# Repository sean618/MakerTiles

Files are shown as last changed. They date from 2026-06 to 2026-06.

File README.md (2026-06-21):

# MakerTiles

MakerTiles is a system of modular, snap-together electronic tiles. Each tile is a
small STM32-based board with a single job — a strip of LEDs, a joystick, a motor,
a distance sensor, a screen, a speaker, and so on. Tiles connect on a shared bus,
a USB tile bridges the bus to a PC, and a Python daemon on the PC discovers every
connected tile and lets you read its inputs and drive its outputs.

This repository holds the whole stack: the **hardware** (KiCad board designs), the
**firmware** (STM32 board projects + shared driver libraries), the **protocols**
that move data over the bus, and the **daemon** that talks to it all from a PC.

```
    [ tile ]──[ tile ]──[ tile ]── … ──[ USB tile ]──USB──▶ [ PC / Python daemon ]
       └───────────────────────────────────┘
          shared SPI bus  (MicroBus + Field Protocol)
```

## How it fits together

Two protocols stacked on top of each other carry everything:

- **MicroBus** — the transport. A master/multi-node protocol over a shared
  SPI-style link between microcontrollers, built for speed and very low RAM:
  fixed-size packets, a time-slotted schedule the master broadcasts in every
  packet, and a small per-node sliding window that gives reliable, in-order
  delivery with no dynamic allocation.
- **Field Protocol** — the application layer. Rides inside a MicroBus packet and
  describes each tile as a set of named, typed **fields** (e.g. a LED strip's
  colour, a dial's position). The daemon enumerates tiles, reads their field
  tables, and gets/sets field values without knowing the tile type in advance.

One tile acts as the **master** (the USB tile, which also bridges the bus to a
host PC). Every other tile is a **node**. On the PC, the daemon opens the USB
serial port, discovers the attached tiles, and exposes each one as an object you
can interact with.

## Repository layout

```
hardware/        KiCad designs for every tile (Boards/) + shared symbol/footprint
                 libraries, 3D models and BOMs (Libraries/). Old/ holds retired
                 prototype boards.

firmware/        STM32 firmware.
  Boards/          One STM32CubeIDE project per tile (Button, LedStrip, Motor,
                   Joystick, Screen, USB, …). Mostly STM32G030 nodes; the USB
                   master is an STM32F103.
  Libraries/       Shared C/C++ drivers used across boards (ledStrip, screen,
                   imu, speaker, servos, …) plus helpers (myAssert, fonts).
  Documents/       NewBoardSetup.txt — the checklist for bringing up a new tile
                   (CubeMX peripheral config + firmware wiring).

protocol/        The shared protocol code, host-buildable and testable.
  microbus/        MicroBus transport (C++). Leaf component.
  fieldprotocol/   Field Protocol (C++), depends on microbus. Also built as the
                   masterNodeSystem shared library the Python daemon loads.
  stm32/           STM32 glue binding the protocols to real SPI hardware
                   (stm32F1SpiMaster, stm32Node). Boards reach this via a
                   Core/stm32 symlink.

daemon/          Python daemon (the PC side). Opens the USB serial port, runs
                   board discovery, and drives tiles over the Field Protocol.
                   src/makertiles/ is the package; tests/ holds its test suites.

tests/system/    Full C stack (node + master) over the real MicroBus, in-process.

tools/           Helper scripts (e.g. logparser.py).
```

## The PC daemon

The daemon is a Python package (`makertiles`, src-layout under `daemon/`). At a
high level you point it at a serial port and it hands you back the discovered
tiles:

```python
import makertiles

tiles, manager = makertiles.start(port_name="/dev/ttyUSB0")

tiles.led_strip.colour = makertiles.red   # set an output field
position = tiles.dial.position             # read an input field
```

It can drive the C protocol two ways: over **serial** to real hardware in
production, or — in tests — by loading the `masterNodeSystem` shared library
directly via `ctypes`, so the real Python daemon exercises the real C protocol
without any hardware attached. That same library is what catches drift between
the C and Python sides of the wire contract.

Optional extras: `Pillow` (`images`) for the screen image-drawing helpers.

## Building and testing

The C components and the Python daemon build in one CMake tree, and every test
suite runs from a single command:

```bash
./build_and_test.sh
```

This configures, builds (MicroBus, the Field Protocol + its shared library, and
the system test), then runs `ctest`. Python test deps (`pytest`, `pyserial`) are
installed automatically if missing.

To re-run only the failures, verbosely:

```bash
ctest --test-dir build --rerun-failed --output-on-failure
```

### Test suites

| CTest name | What it covers |
|---|---|
| `microbus_unit` | MicroBus transport unit tests (host). |
| `fieldprotocol_unit` | Field Protocol unit tests against a mock MicroBus. |
| `system_integration` | Full C stack (node + master) over the real MicroBus. |
| `python_unit` | Python Field-Protocol encode/decode round trips. |
| `python_integration` | The real Python daemon driving the C protocol via the .so.  |

`python_integration` is the suite that exercises both languages together, so it
is the one that catches C↔Python wire-contract drift.

The firmware board projects under `firmware/Boards/` are separate
STM32CubeIDE/CMake projects and are **not** part of the host build above — they
are flashed to real tiles. See `firmware/Documents/NewBoardSetup.txt` for the
per-board hardware and firmware bring-up checklist.

## Building firmware for a tile

Each `firmware/Boards/<Tile>/` directory is its own STM32 project (`.ioc` for
CubeMX, a linker script for the target part, and CubeIDE debug launch configs).
Nodes are generally STM32G030; the USB master is an STM32F103. The protocol
sources are shared into each board via symlinks (`Core/stm32`,
`Core/Libraries`, etc.) rather than copied — see the setup checklist for the
exact links and the required SPI/timer/interrupt peripheral configuration.

## License

Released under the [MIT License](LICENSE).

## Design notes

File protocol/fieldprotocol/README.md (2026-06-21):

# Field Protocol (C++23)

An idiomatic C++23 port of the Field Protocol firmware/daemon library. The code
implements a small field-discovery and get/set protocol between a daemon, a bus
master, and many nodes, with a wire format that is preserved byte-for-byte from
the original.

## Building

The project builds under **both `g++` and `clang++`** as standards-conformant
C++23 (no compiler extensions).

### With CMake

```bash
./build.sh            # configures + builds into ./build
cd build && ctest     # runs the test executable
```

This produces two artifacts:

- `fieldprotocol_tests` — the test executable (built with `USE_FP_DAEMON` and
  `USE_MOCK_MICROBUS`). Running it prints `Passed` on success.
- `libmasterNodeSystem` — the shared library exposing the `extern "C"` entry
  points the Python daemon loads via `ctypes` (built with `USE_MOCK_MICROBUS`
  only; no C++ daemon).

### Without CMake

`build_and_test.sh` builds both targets directly with a compiler of your choice
and asserts the suite prints `Passed`:

```bash
./build_and_test.sh g++ clang++   # build + test under both
CXX=g++ ./build_and_test.sh       # or pick one via $CXX
```

## Layout

- `src/` — the protocol library, header-only: `fpCommon.hpp`, `fpNode.hpp`,
  `fpMaster.hpp`, `fpDaemon.hpp`. Each class is fully defined (declaration and
  implementation) in its header, so consumers just `#include` it.
- `test/` — test drivers, board fixtures, and the three interchangeable
  transports (direct-call, mock microbus, real microbus) plus the Python API
  shim (`pythonApi.cpp`).

## What changed from the C version

The original was C-style code compiled as C++. The port keeps the on-the-wire
behaviour identical while adopting modern C++ idioms:

- Everything lives in `namespace fp`. C headers (`stdint.h`, …) became their
  `<cstdint>` equivalents; `NULL` became `nullptr`; casts are now
  `static_cast`/`reinterpret_cast`. `fpCommon.hpp` pulls the fixed-width integer
  types into scope with `using` declarations, so the code writes `uint8_t`
  rather than `std::uint8_t`.
- Tag enums became scoped `enum class : uint8_t`. `FieldFlags` gained
  `operator|`/`&` and `isGettable`/`isSettable`/`isJoined` helpers. The X-macro
  command table became a `commandName()` function.
- The transport, previously a struct of four function pointers plus an opaque
  `void* state`, is now the abstract base class `FpInterface`; each transport
  (mock, direct-call, microbus) derives from it and owns its own state. The old
  `getNodeId` callback folded into a virtual method.
- `tFpNode`/`tFpMaster`/`tFpDaemon` became the classes `Node`/`Master`/`Daemon`
  with `init(...)` constructors-in-spirit and member functions in place of the
  free `fpXxx(&obj, …)` functions. The master's two callbacks became
  `std::function`s.
- Board and field strings became `std::string`, which removed the daemon's
  manual `malloc`/`free` bookkeeping. The daemon now owns discovered boards via
  `std::unique_ptr`.
- The packed wire structs keep `#pragma pack` and their exact field order, so
  `RawBusFieldPacket` (6-byte header + 186-byte payload) and
  `RawDaemonFieldPacket` are byte-identical to the original.

Two latent out-of-bounds reads in the original test fixtures (an 8-byte field
backed by a 1-byte variable, and a 2-byte-element stream backed by a 1-byte
array) were fixed by widening the backing storage to match the declared field
sizes; the wire bytes and field tables are otherwise unchanged.

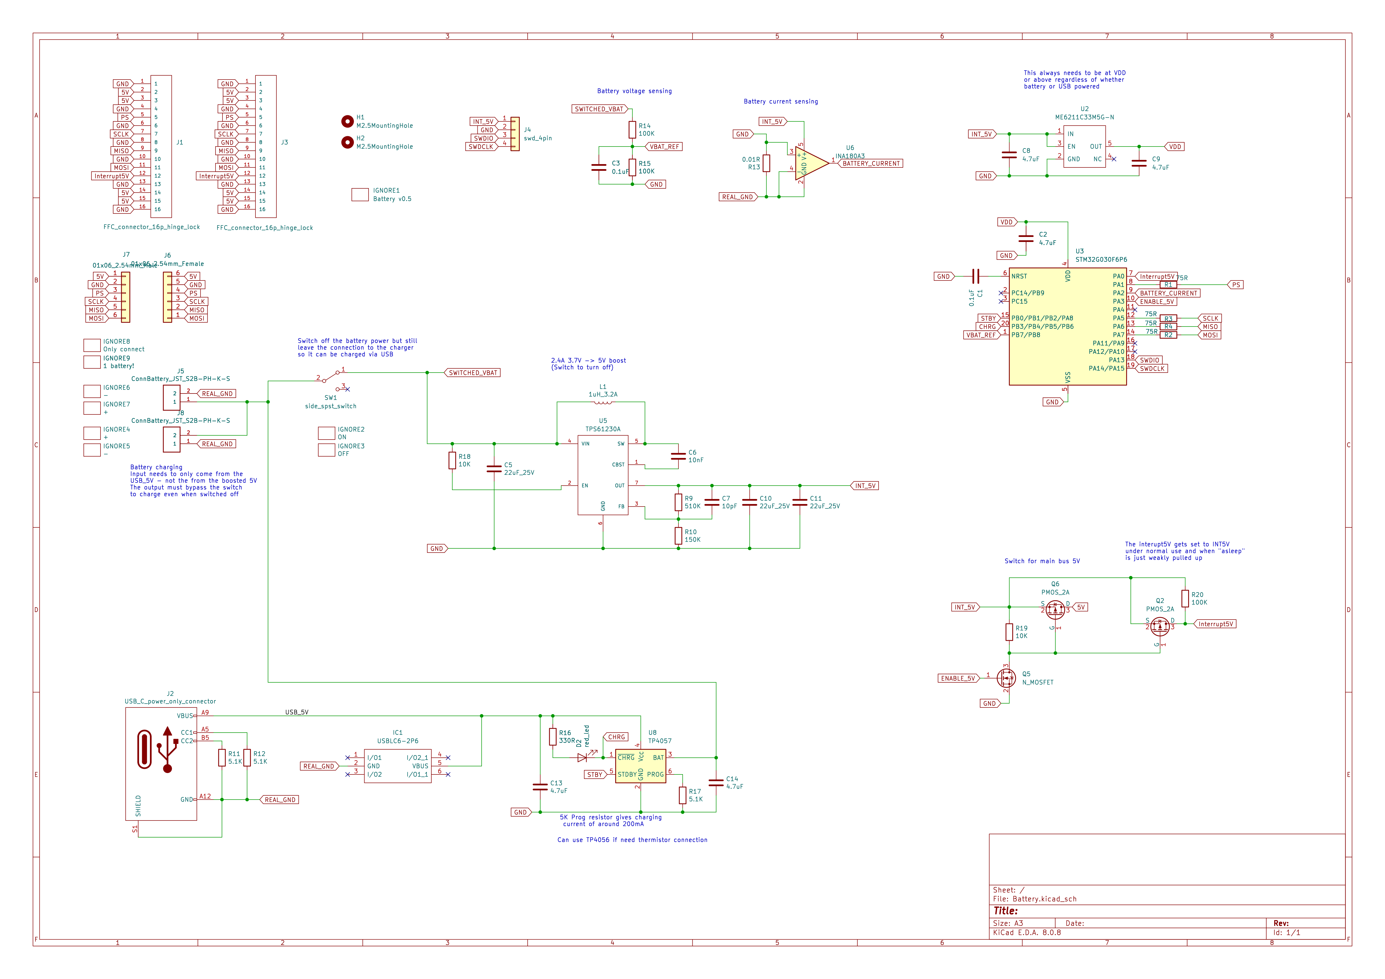
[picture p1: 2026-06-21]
hardware/Boards/Battery/v0.10/Battery.png

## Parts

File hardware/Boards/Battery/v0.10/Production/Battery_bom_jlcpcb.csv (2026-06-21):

Comment | Designator | Footprint | LCSC Part Number
4.7uF | C9,C4,C13,C14,C8,C2 | C_0402_1005Metric | C23733
FFC_connector_16p_hinge_lock | J1,J3 | FFC_connector_16p_hinge_lock | C262665
0.01R | R13 | R_0805_2012Metric | C2912728
PMOS_2A | Q6,Q2 | SOT-23 | C306862
22uF_25V | C10,C5,C11 | C_0805_2012Metric | C602037
red_led | D2 | LED_SML-D12D1WT86 | C2286
side_spst_switch | SW1 | side_spst_switch | C431548
10pF | C7 | C_0402_1005Metric | C32949
ConnBattery_JST_S2B-PH-K-S | J5,J8 | JST_PH_S2B-PH-K_1x02_P2.00mm_Horizontal | C173752
USB_C_power_only_connector | J2 | USB_C_Receptacle_power_only_6P | C283540
INA180A3 | U6 | SOT-23-5 | C122882
USBLC6-2P6 | IC1 | USBLC6-2P6 | C2827693
TP4057 | U8 | SOT-23-6 | C5380673
10K | R5,R6,R18,R19 | R_0402_1005Metric | C25744
TPS61230A | U5 | TPS61230A | C376005
ME6211C33M5G-N | U2 | SOT-23-5 | C81233
0.1uF | C1,C3,C12 | C_0402_1005Metric | C1525
150K | R10 | R_0402_1005Metric | C25755
510K | R9 | R_0402_1005Metric | C11616
330R | R16 | R_0402_1005Metric | C25104
75R | R2,R3,R4,R1 | R_0402_1005Metric | C25133
XB7608AJ | U4 | XB7608AJ | C2681921
STM32G030F6P6 | U3 | TSSOP-20_4.4x6.5mm_P0.65mm | C529330
5.1K | R12,R17,R11 | R_0402_1005Metric | C25905
100K | R15,R14,R20 | R_0402_1005Metric | C25741
1uH_3.2A | L1 | L_1008_2520Metric | C315711
1K | R7 | R_0402_1005Metric | C11702
N_MOSFET | Q5 | SOT-23 | C8545
TPS2116DRL | U1 | SOT-583-8 | C3235557
10nF | C6 | C_0402_1005Metric | C15195
01x06_2.54mm_Female | J6 | 01x06_2.54mm_Female | C5142239
01x06_2.54mm_Male | J7 | 01x06_2.54mm_Male | C5242199

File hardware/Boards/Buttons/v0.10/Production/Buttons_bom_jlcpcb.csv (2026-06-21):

Comment | Designator | Footprint | LCSC Part Number
4.7uF | C9,C8,C2 | C_0402_1005Metric | C23733
FFC_connector_16p_hinge_lock | J5,J3 | FFC_connector_16p_hinge_lock | C262665
button_6x6x7 | SW1,SW2,SW4,SW3,SW6 | SW_SPST_PTS645 | C381064
10K | R9,R6,R8,R5,R7 | R_0402_1005Metric | C25744
ME6211C33M5G-N | U2 | SOT-23-5 | C81233
75R | R2,R3,R4,R1 | R_0402_1005Metric | C25133
STM32G030F6P6 | U3 | TSSOP-20_4.4x6.5mm_P0.65mm | C529330
0.1uF | C1 | C_0402_1005Metric | C1525
1N4148W | D2 | D_SOD-123 | C81598
01x06_2.54mm_Male | J1 | 01x06_2.54mm_Male | C5242199
01x06_2.54mm_Female | J2 | 01x06_2.54mm_Female | C5142239

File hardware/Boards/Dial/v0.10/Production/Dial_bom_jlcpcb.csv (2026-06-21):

Comment | Designator | Footprint | LCSC Part Number
4.7uF | C9,C8,C2 | C_0402_1005Metric | C23733
FFC_connector_16p_hinge_lock | J1,J2 | FFC_connector_16p_hinge_lock | C262665
STM32C011F6Px | U3 | TSSOP-20_4.4x6.5mm_P0.65mm | C5456198
1N4148W | D2 | D_SOD-123 | C81598
ME6211C33M5G-N | U2 | SOT-23-5 | C81233
75R | R2,R4,R1,R3 | R_0402_1005Metric | C25133
RotaryEncoder_Switch | SW7 | RotaryEncoderEC12D | C112349
10K | R5 | R_0402_1005Metric | C25744
0.1uF | C1 | C_0402_1005Metric | C1525
01x06_2.54mm_Female | J5 | 01x06_2.54mm_Female | C5142239
01x06_2.54mm_Male | J3 | 01x06_2.54mm_Male | C5242199

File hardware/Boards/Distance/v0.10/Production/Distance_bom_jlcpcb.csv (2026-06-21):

Comment | Designator | Footprint | LCSC Part Number
4.7uF | C9,C8,C5,C3,C4 | C_0402_1005Metric | C23733
12pF | C6,C7 | C_0402_1005Metric | C1547
FFC_connector_16p_hinge_lock | J3,J5 | FFC_connector_16p_hinge_lock | C262665
75R | R8,R10,R9,R7 | R_0402_1005Metric | C25133
0.1uF | C11 | C_0402_1005Metric | C1525
10K | R5,R6 | R_0402_1005Metric | C25744
STM32F103C8T6 | U3 | LQFP-48_7x7mm_P0.5mm | C8734
ME6211C33M5G-N | U2 | SOT-23-5 | C81233
VL53L3CXV0DH | U1 | VL53L3CXV0DH | C1864163
Crystal_16M_small | Y1 | Crystal_SMD_2016-4Pin_2.0x1.6mm | C252270
01x06_2.54mm_Male | J1 | 01x06_2.54mm_Male | C5242199
01x06_2.54mm_Female | J2 | 01x06_2.54mm_Female | C5142239

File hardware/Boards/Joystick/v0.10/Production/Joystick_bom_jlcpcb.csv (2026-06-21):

Comment | Designator | Footprint | LCSC Part Number
4.7uF | C9,C8,C2 | C_0402_1005Metric | C23733
Joystick | U1 | Joystick | C146170
FFC_connector_16p_hinge_lock | J5,J2 | FFC_connector_16p_hinge_lock | C262665
ME6211C33M5G-N | U2 | SOT-23-5 | C81233
75R | R2,R4,R1,R3 | R_0402_1005Metric | C25133
STM32G030F6P6 | U3 | TSSOP-20_4.4x6.5mm_P0.65mm | C529330
10K | R6 | R_0402_1005Metric | C25744
0.1uF | C1 | C_0402_1005Metric | C1525
01x06_2.54mm_Male | J1 | 01x06_2.54mm_Male | C5242199
01x06_2.54mm_Female | J3 | 01x06_2.54mm_Female | C5142239

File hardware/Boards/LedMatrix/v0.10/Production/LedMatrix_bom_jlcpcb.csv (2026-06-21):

Comment | Designator | Footprint | LCSC Part Number
WS2812B | D34,D48,D12,D2,D37,D47,D39,D42,D11,D3,D18,D16,D15,D29,D17,D38,D28,D4,D36,D43,D21,D14,D26,D24,D8,D22,D40,D32,D6,D10,D49,D44,D41,D35,D31,D33,D20,D30,D46,D9,D27,D13,D23,D1,D25,D19,D7,D5,D45 | LED_WS2812B_PLCC4_5.0x5.0mm_P3.2mm | C2843785
N_MOSFET | Q1 | SOT-23 | C8545
STM32G030F6P6 | U2 | TSSOP-20_4.4x6.5mm_P0.65mm | C529330
FFC_connector_16p_hinge_lock | J4,J5 | FFC_connector_16p_hinge_lock | C262665
22uF_10V | C8,C6,C11,C15,C16,C7,C13,C12 | C_0603_1608Metric | C86295
4.7uF | C3,C2,C1 | C_0402_1005Metric | C23733
75R | R1,R3,R5,R6 | R_0402_1005Metric | C25133
1K | R4,R2 | R_0402_1005Metric | C11702
01x06_2.54mm_Male | J1 | 01x06_2.54mm_Male | C5242199
0.1uF | C4 | C_0402_1005Metric | C1525
ME6211C33M5G-N | U1 | SOT-23-5 | C81233
01x06_2.54mm_Female | J2 | 01x06_2.54mm_Female | C5142239

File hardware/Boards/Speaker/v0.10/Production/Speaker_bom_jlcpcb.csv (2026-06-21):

Comment | Designator | Footprint | LCSC Part Number
SpeakerSmt | LS2 | Speaker1.8x1.8 | C48542868
FFC_connector_16p_hinge_lock | J12,J13 | FFC_connector_16p_hinge_lock | C262665
2p_picoblade | J2 | Molex_PicoBlade_53261-0271_1x02-1MP_P1.25mm_Horizontal | C2905009
4.7uF | C9,C11,C8,C12 | C_0402_1005Metric | C23733
220pF | C10,C4 | C_0402_1005Metric | C1530
75R | R7,R4,R9,R6 | R_0402_1005Metric | C25133
01x06_2.54mm_Male | J1 | 01x06_2.54mm_Male | C5242199
01x06_2.54mm_Female | J3 | 01x06_2.54mm_Female | C5142239
ME6211C33M5G-N | U2 | SOT-23-5 | C81233
750K | R2 | R_0402_1005Metric | C43291
0.1uF | C15 | C_0402_1005Metric | C1525
STM32G030F6P6 | U3 | TSSOP-20_4.4x6.5mm_P0.65mm | C529330
MAX98357AEWL+T | U1 | WLP-9_1.448x1.468mm_Layout3x3_P0.4mm_Ball0.27mm_Pad0.25mm | C2682619

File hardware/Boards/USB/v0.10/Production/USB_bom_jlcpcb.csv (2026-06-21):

Comment | Designator | Footprint | LCSC Part Number
4.7uF | C9,C2,C8,C5,C1 | C_0402_1005Metric | C23733
1.5K | R12 | R_0402_1005Metric | C25867
12pF | C6,C7 | C_0402_1005Metric | C1547
FFC_connector_16p_hinge_lock | J5,J6 | FFC_connector_16p_hinge_lock | C262665
STM32F103C8T6 | U1 | LQFP-48_7x7mm_P0.5mm | C8734
75R | R7,R4,R5,R6 | R_0402_1005Metric | C25133
ME6211C33M5G-N | U2 | SOT-23-5 | C81233
5.1K | R2,R1 | R_0402_1005Metric | C25905
USBLC6-4SC6 | IC1 | SOT-23-6 | C558419
Crystal_16M_small | Y2 | Crystal_SMD_2016-4Pin_2.0x1.6mm | C252270
0.1uF | C4 | C_0402_1005Metric | C1525
USB_C_connector_16P | J2 | USB_C_Receptacle_16P | C319148
01x06_2.54mm_Male | J1 | 01x06_2.54mm_Male | C5242199
01x06_2.54mm_Female | J3 | 01x06_2.54mm_Female | C5142239

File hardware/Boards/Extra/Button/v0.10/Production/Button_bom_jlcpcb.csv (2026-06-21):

Comment | Designator | Footprint | LCSC Part Number
4.7uF | C9,C8,C2 | C_0402_1005Metric | C23733
FFC_connector_16p_hinge_lock | J1,J3 | FFC_connector_16p_hinge_lock | C262665
10K | R5 | R_0402_1005Metric | C25744
button_6x6x7 | SW2 | SW_SPST_PTS645 | C381064
1K | R6 | R_0402_1005Metric | C11702
ME6211C33M5G-N | U2 | SOT-23-5 | C81233
1N4148W | D3 | D_SOD-123 | C81598
75R | R2,R3,R4,R1 | R_0402_1005Metric | C25133
STM32G030F6P6 | U3 | TSSOP-20_4.4x6.5mm_P0.65mm | C529330
ws2812b_1615 | D2 | WS2812B_1615 | C5349954
N_MOSFET | Q1 | SOT-23 | C8545
0.1uF | C1 | C_0402_1005Metric | C1525
01x06_2.54mm_Female | J5 | 01x06_2.54mm_Female | C5142239
01x06_2.54mm_Male | J2 | 01x06_2.54mm_Male | C5242199

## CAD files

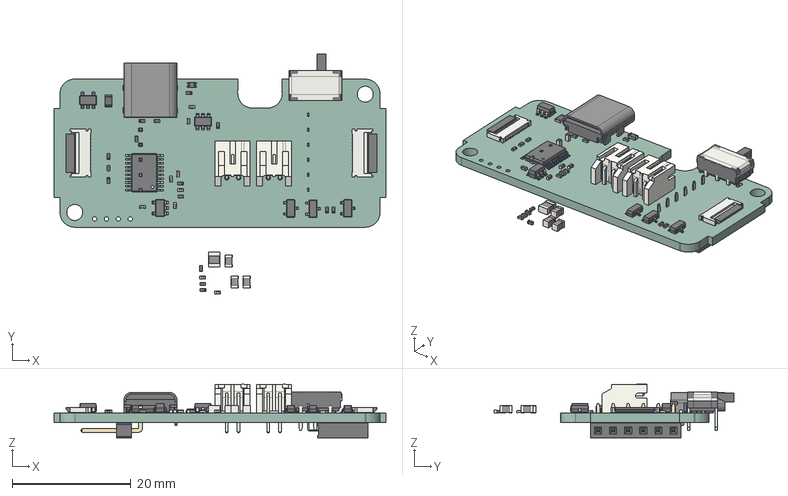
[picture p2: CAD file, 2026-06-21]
hardware/Boards/Battery/v0.10/Battery.step
56.0 x 40.5 x 9.09 mm
C_0402_1005Metric x 9
Molex_502250_2191 x 2
R_0805_2012Metric
SOT_23 x 3
C_0805_2012Metric x 3
D_0603
SW_CuK_JS202011AQN_DPDT_Angled
JST_S2B_PH_K x 2
USB_C_Receptacle_GCT_USB4085
SOT_23_5 x 2
SOT_23_6
R_0402_1005Metric x 15
TSSOP_20_44x65mm_P065mm
L_1008_2520Metric
PinSocket_1x06_P2.54mm_Horizontal
PinHeader_1x06_P254mm_Horizontal
Battery_PCB

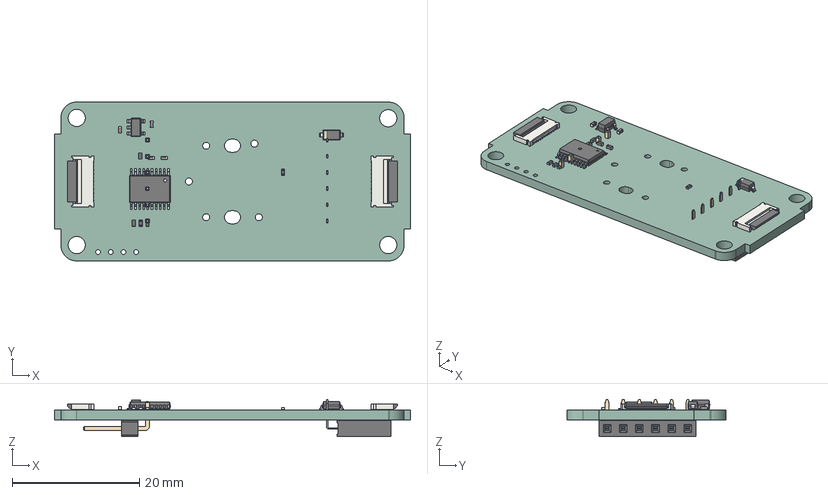
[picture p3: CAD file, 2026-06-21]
hardware/Boards/Dial/v0.10/Dial.step
56.0 x 25.0 x 5.84 mm
C_0402_1005Metric x 4
Molex_502250_2191 x 2
D_SOD_123
SOT_23_5
R_0402_1005Metric x 5
TSSOP_20_44x65mm_P065mm
PinSocket_1x06_P2.54mm_Horizontal
PinHeader_1x06_P254mm_Horizontal
Dial_PCB

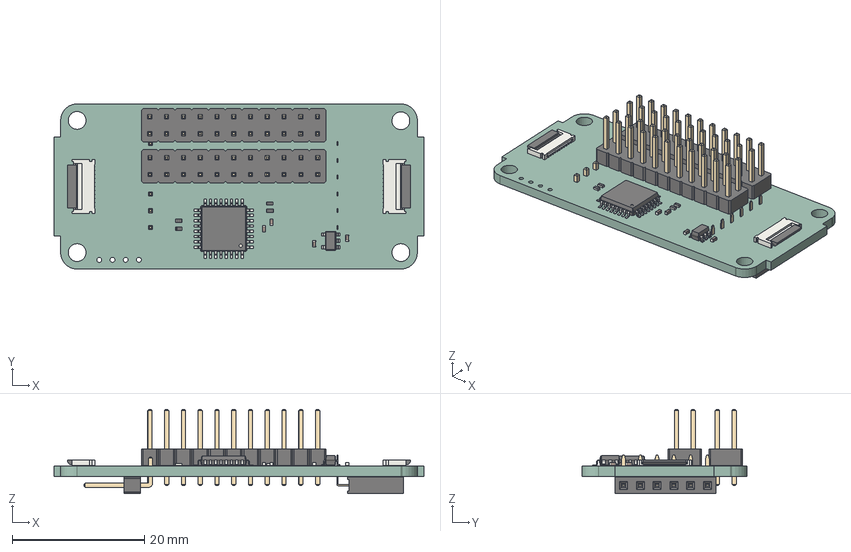
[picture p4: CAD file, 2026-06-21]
hardware/Boards/Extra/ButtonExpansion/v0.5/ButtonExpansion.step
56.0 x 25.0 x 12.8 mm
C_0402_1005Metric x 4
Molex_502250_2191 x 2
R_0402_1005Metric x 4
PinHeader_2x11_P254mm_Vertical x 2
SOT_23_5
LQFP_32_7x7mm_P08mm
PinHeader_1x06_P254mm_Horizontal
PinSocket_1x06_P2.54mm_Horizontal
ButtonExpansion_PCB

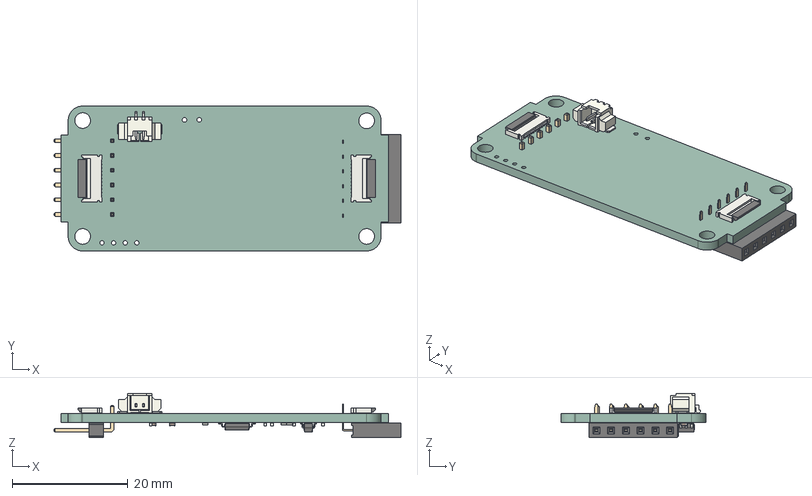
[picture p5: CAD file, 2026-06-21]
hardware/Boards/Speaker/v0.10/Speaker.step
59.9 x 25.0 x 7.64 mm
Molex_502250_2191 x 2
Molex_53261_0271
C_0402_1005Metric x 7
R_0402_1005Metric x 5
PinHeader_1x06_P254mm_Horizontal
PinSocket_1x06_P2.54mm_Horizontal
SOT_23_5
TSSOP_20_44x65mm_P065mm
Speaker_PCB

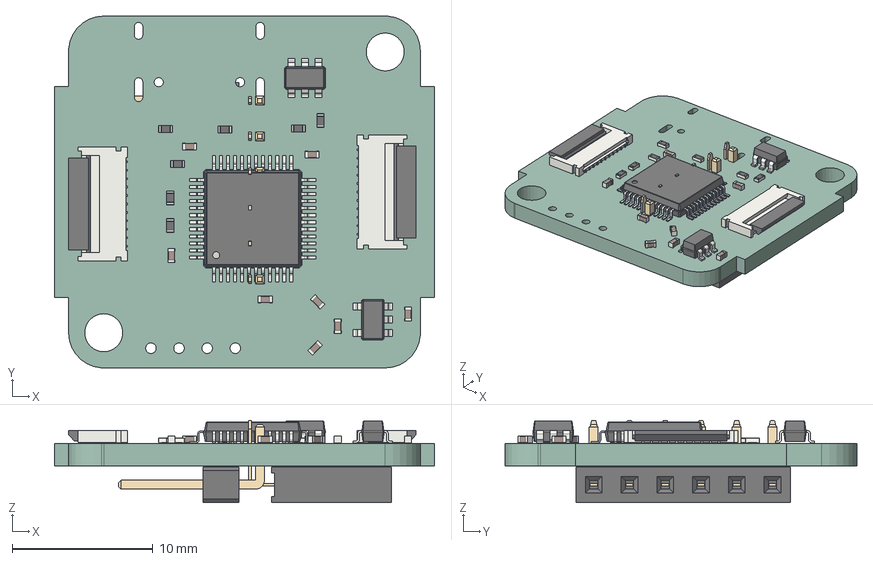
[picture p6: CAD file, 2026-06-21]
hardware/Boards/USB/v0.10/USB.step
27.0 x 25.0 x 5.84 mm
C_0402_1005Metric x 8
R_0402_1005Metric x 7
Molex_502250_2191 x 2
LQFP_48_7x7mm_P05mm
SOT_23_5
SOT_23_6
PinHeader_1x06_P254mm_Horizontal
PinSocket_1x06_P2.54mm_Horizontal
USB_PCB

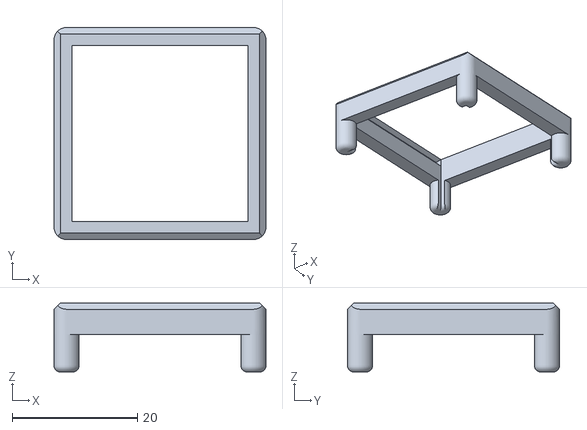
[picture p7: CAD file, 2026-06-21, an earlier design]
hardware/Boards/Battery/v0.5/Ring.stl
33.8 x 33.8 x 11.0

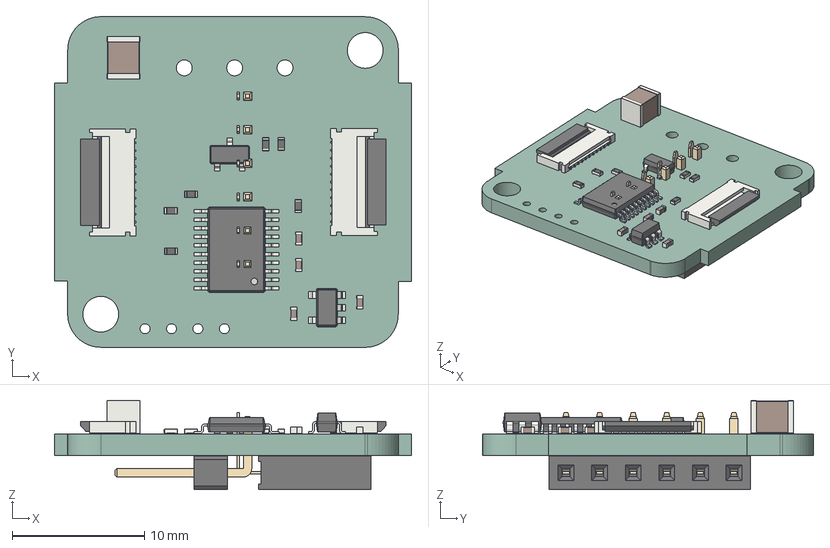
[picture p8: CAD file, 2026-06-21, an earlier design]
hardware/Boards/LED/v0.10/LED.step
27.0 x 25.0 x 6.74 mm
C_0402_1005Metric x 4
Molex_502250_2191 x 2
C_1210_3225Metric
R_0402_1005Metric x 6
SOT_23_5
SOT_23
TSSOP_20_44x65mm_P065mm
PinHeader_1x06_P254mm_Horizontal
PinSocket_1x06_P2.54mm_Horizontal
LED_PCB

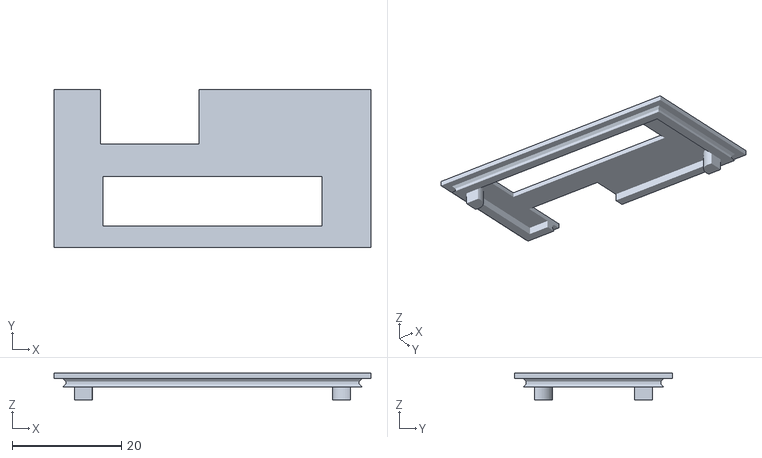
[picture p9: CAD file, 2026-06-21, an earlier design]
hardware/Boards/Motor/v0.7/MotorLid.stl
58.0 x 29.0 x 4.90

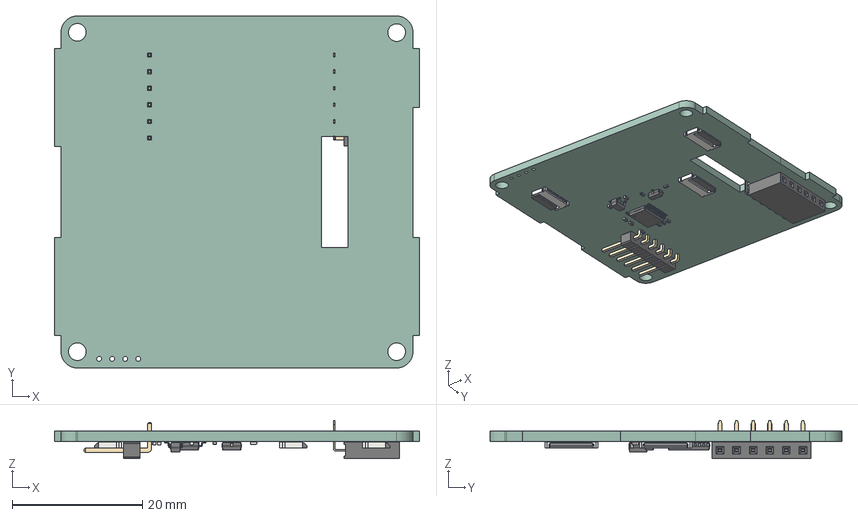
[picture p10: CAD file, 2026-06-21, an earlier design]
hardware/Boards/Screen/v0.5/Screen.step
56.0 x 54.0 x 5.84 mm
C_0402_1005Metric x 4
Molex_502250_2191 x 3
SOT_23_5
R_0402_1005Metric x 6
TSSOP_20_44x65mm_P065mm
SOT_23
PinSocket_1x06_P2.54mm_Horizontal
PinHeader_1x06_P254mm_Horizontal
Screen_PCB

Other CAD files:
hardware/Boards/Joystick/v0.10/Joystick.step
hardware/Boards/Joystick/v0.5/Joystick.step
hardware/Boards/Battery/v0.5/Battery.step
hardware/Boards/Motor/v0.7/Motor.step

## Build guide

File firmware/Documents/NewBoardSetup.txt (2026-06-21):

*************** Node **************

HW:
    - SWD!!!
    - Crystal?
    - SPI slave configured:
        - Motorola, 16 bits, MSB first
        - CPOL - low
        - CPHA - 1 edge
        - CRC 16 bits Enabled (X0 + X1 + X2, NSS software)
        - Tx DMA normal - half word
        - Rx DMA normal - half word
    - External interrupt (on rising edge) (enable NVIC) - high priority!
    - A timer set to count every 200us - update interrupt - for FieldProtocol? - low priority
    - NVIC: EXTI interrupt for protocol must be same level or higher than protocol SPI DMA channel interrupts!!
        - SPI DMA channels - NVIC:0
        - EXTI0 - NVIC:0

FW:
    - cd to Board and create symbolic links for:
        ln -s ../../../../FieldProtocol/src Core/FieldProtocol
        ln -s ../../../../Microbus/src Core/Microbus
        ln -s ../../../Libraries/ Core/Libraries
    - Create a board.c file in src
    - Create a project.h file in inc
    - In main.c define:
        extern void boardInit();
        extern void boardLoop();
    - Compiler:
        - optimise for debug -Og

    - nodeInit(tNode * node, 
                    uint64_t uniqueId,
                    uint8_t maxTxPacketEntries, 
                    tPacketEntry txPacketEntries[], 
                    uint8_t maxRxPackets, 
                    tPacketEntry rxPackets[],
                    tPacketEntry * rxPacketQueue[]);
    - hwNodeInit(tNode * node, SPI_HandleTypeDef *hspi, uint16_t psGpioPin)
    - Don't need to do anything for interrupts - as it's hardcoded on HAL_GPIO_EXTI_Callback, HAL_SPI_TxRxCpltCallback, HAL_SPI_RxCpltCallback
    - Timer callback should call fpNodeProcessRxTx
    - void fpNodeInit(tFpNode * fpNode, tFpInterface * itf, getNodeIdFn getNodeId, tBoardInfo * boardInfo, tFieldEntry * table);

*************** Master **************

General
=======
HW
    - SWD!!!
    - Crystal 16MHz - high speed RCC
    - clock set to 48MHz
    - SPI master configured:
        - 12 Mhz
        - Motorola, 16 bits, MSB first
        - CPOL - *high*
        - CRC Enabled (X1 + X3, NSS software)
        - Tx DMA normal
        - Rx DMA normal
        - complete interrupt high priority!
    - GPIO output for the PS signal
    - A timer set to count every 1us - update interrupt - for microbusDelay? - med priority
    - A timer set to count every 200us - update interrupt - for FieldProtocol? - low priority
    - USB

FW:
    Create symbolic links for FieldProtocol/src and Microbus/src
    Create a board.c file in src
    In main.c define and call boardInit(), boardLoop()
    In board.c call hwMasterInit
    - Compiler:
        - Add flag USE_SPI_MASTER
        - optimise for debug

Field Protocol
==============

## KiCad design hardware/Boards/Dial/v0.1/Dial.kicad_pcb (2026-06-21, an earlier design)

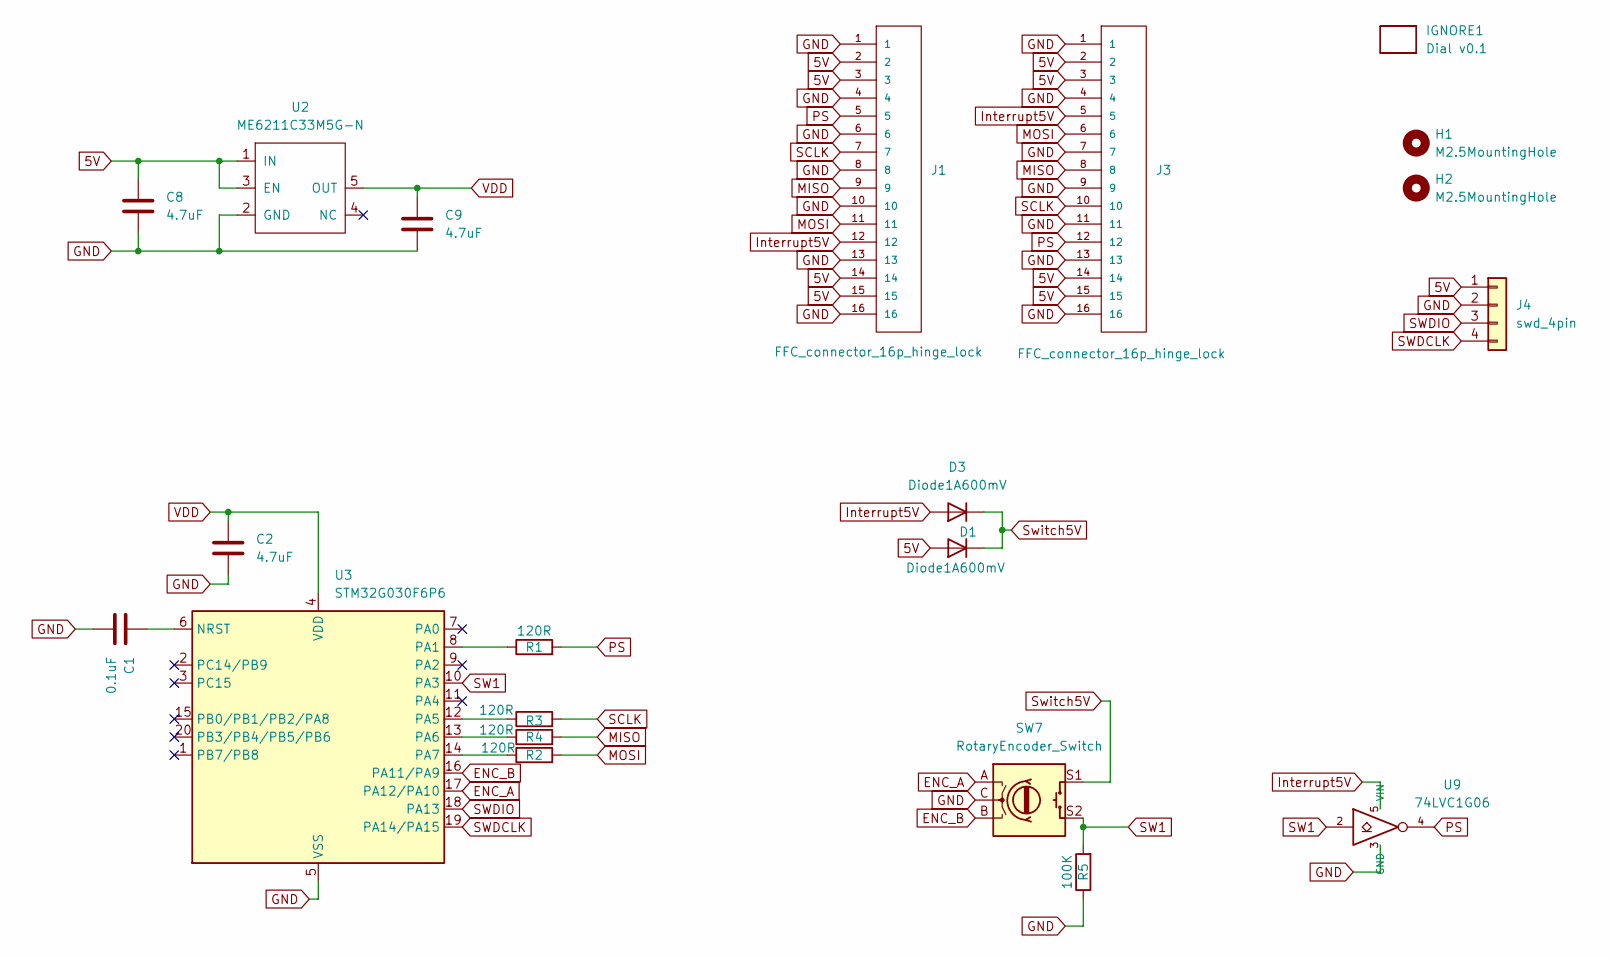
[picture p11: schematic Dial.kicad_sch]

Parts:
C1: 0.1uF; C_0402_1005Metric
C2, C8, C9: 4.7uF; C_0402_1005Metric
D1, D3: Diode1A600mV; D_SOD-323
H1, H2: M2.5MountingHole; MountingHole_2.7mm_M2.5_ISO7380
IGNORE1: Dial v0.1; BoardText
J1, J3: FFC_connector_16p_hinge_lock
J4: swd_4pin; swd_header
R1, R2, R3, R4: 120R; R_0402_1005Metric
R5: 100K; R_0402_1005Metric
SW7: RotaryEncoder_Switch; RotaryEncoderEC12D
U2: ME6211C33M5G-N; SOT-23-5
U3: STM32G030F6P6; TSSOP-20_4.4x6.5mm_P0.65mm
U9: 74LVC1G06; SOT-353_SC-70-5

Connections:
5V: C8.1, D1.2 (A), J1.2, J1.3, J1.14, J1.15, J3.2, J3.3, J3.14, J3.15, J4.1, U2.1 (IN), U2.3 (EN)
ENC_A: SW7.A, U3.17 (PA12/PA10)
ENC_B: SW7.B, U3.16 (PA11/PA9)
GND: C1.2, C2.2, C8.2, C9.2, J1.1, J1.4, J1.6, J1.8, J1.10, J1.13, J1.16, J3.1, J3.4, J3.7, J3.9, J3.11, J3.13, J3.16, J4.2, R5.1, SW7.C, U2.2 (GND), U3.5 (VSS), U9.3 (GND)
Interrupt5V: D3.2 (A), J1.12, J3.5, U9.5 (VIN)
MISO: J1.9, J3.8, R4.2
MOSI: J1.11, J3.6, R2.2
unnamed: C1.1, U3.6 (NRST)
unnamed: R1.1, U3.8 (PA1)
unnamed: R3.1, U3.12 (PA5)
unnamed: R4.1, U3.13 (PA6)
unnamed: R2.1, U3.14 (PA7)
PS: J1.5, J3.12, R1.2, U9.4
SCLK: J1.7, J3.10, R3.2
SW1: R5.2, SW7.S2, U3.10 (PA3), U9.2
SWDCLK: J4.4, U3.19 (PA14/PA15)
SWDIO: J4.3, U3.18 (PA13)
Switch5V: D1.1 (K), D3.1 (K), SW7.S1
VDD: C2.1, C9.1, U2.5 (OUT), U3.4 (VDD)

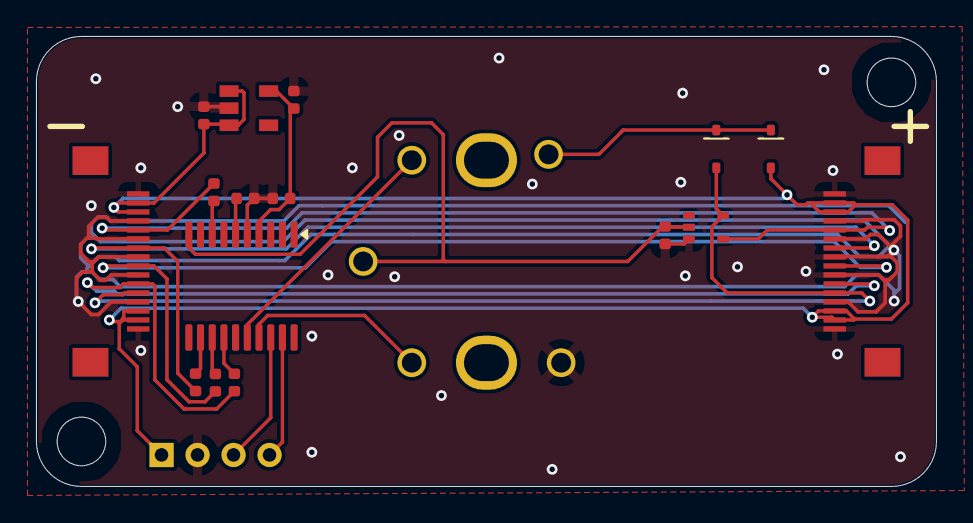
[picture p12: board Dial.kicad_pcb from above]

Board: 2 copper layers, 50.0 x 25.0 mm, 21 parts (0 on the bottom side), 19 nets.

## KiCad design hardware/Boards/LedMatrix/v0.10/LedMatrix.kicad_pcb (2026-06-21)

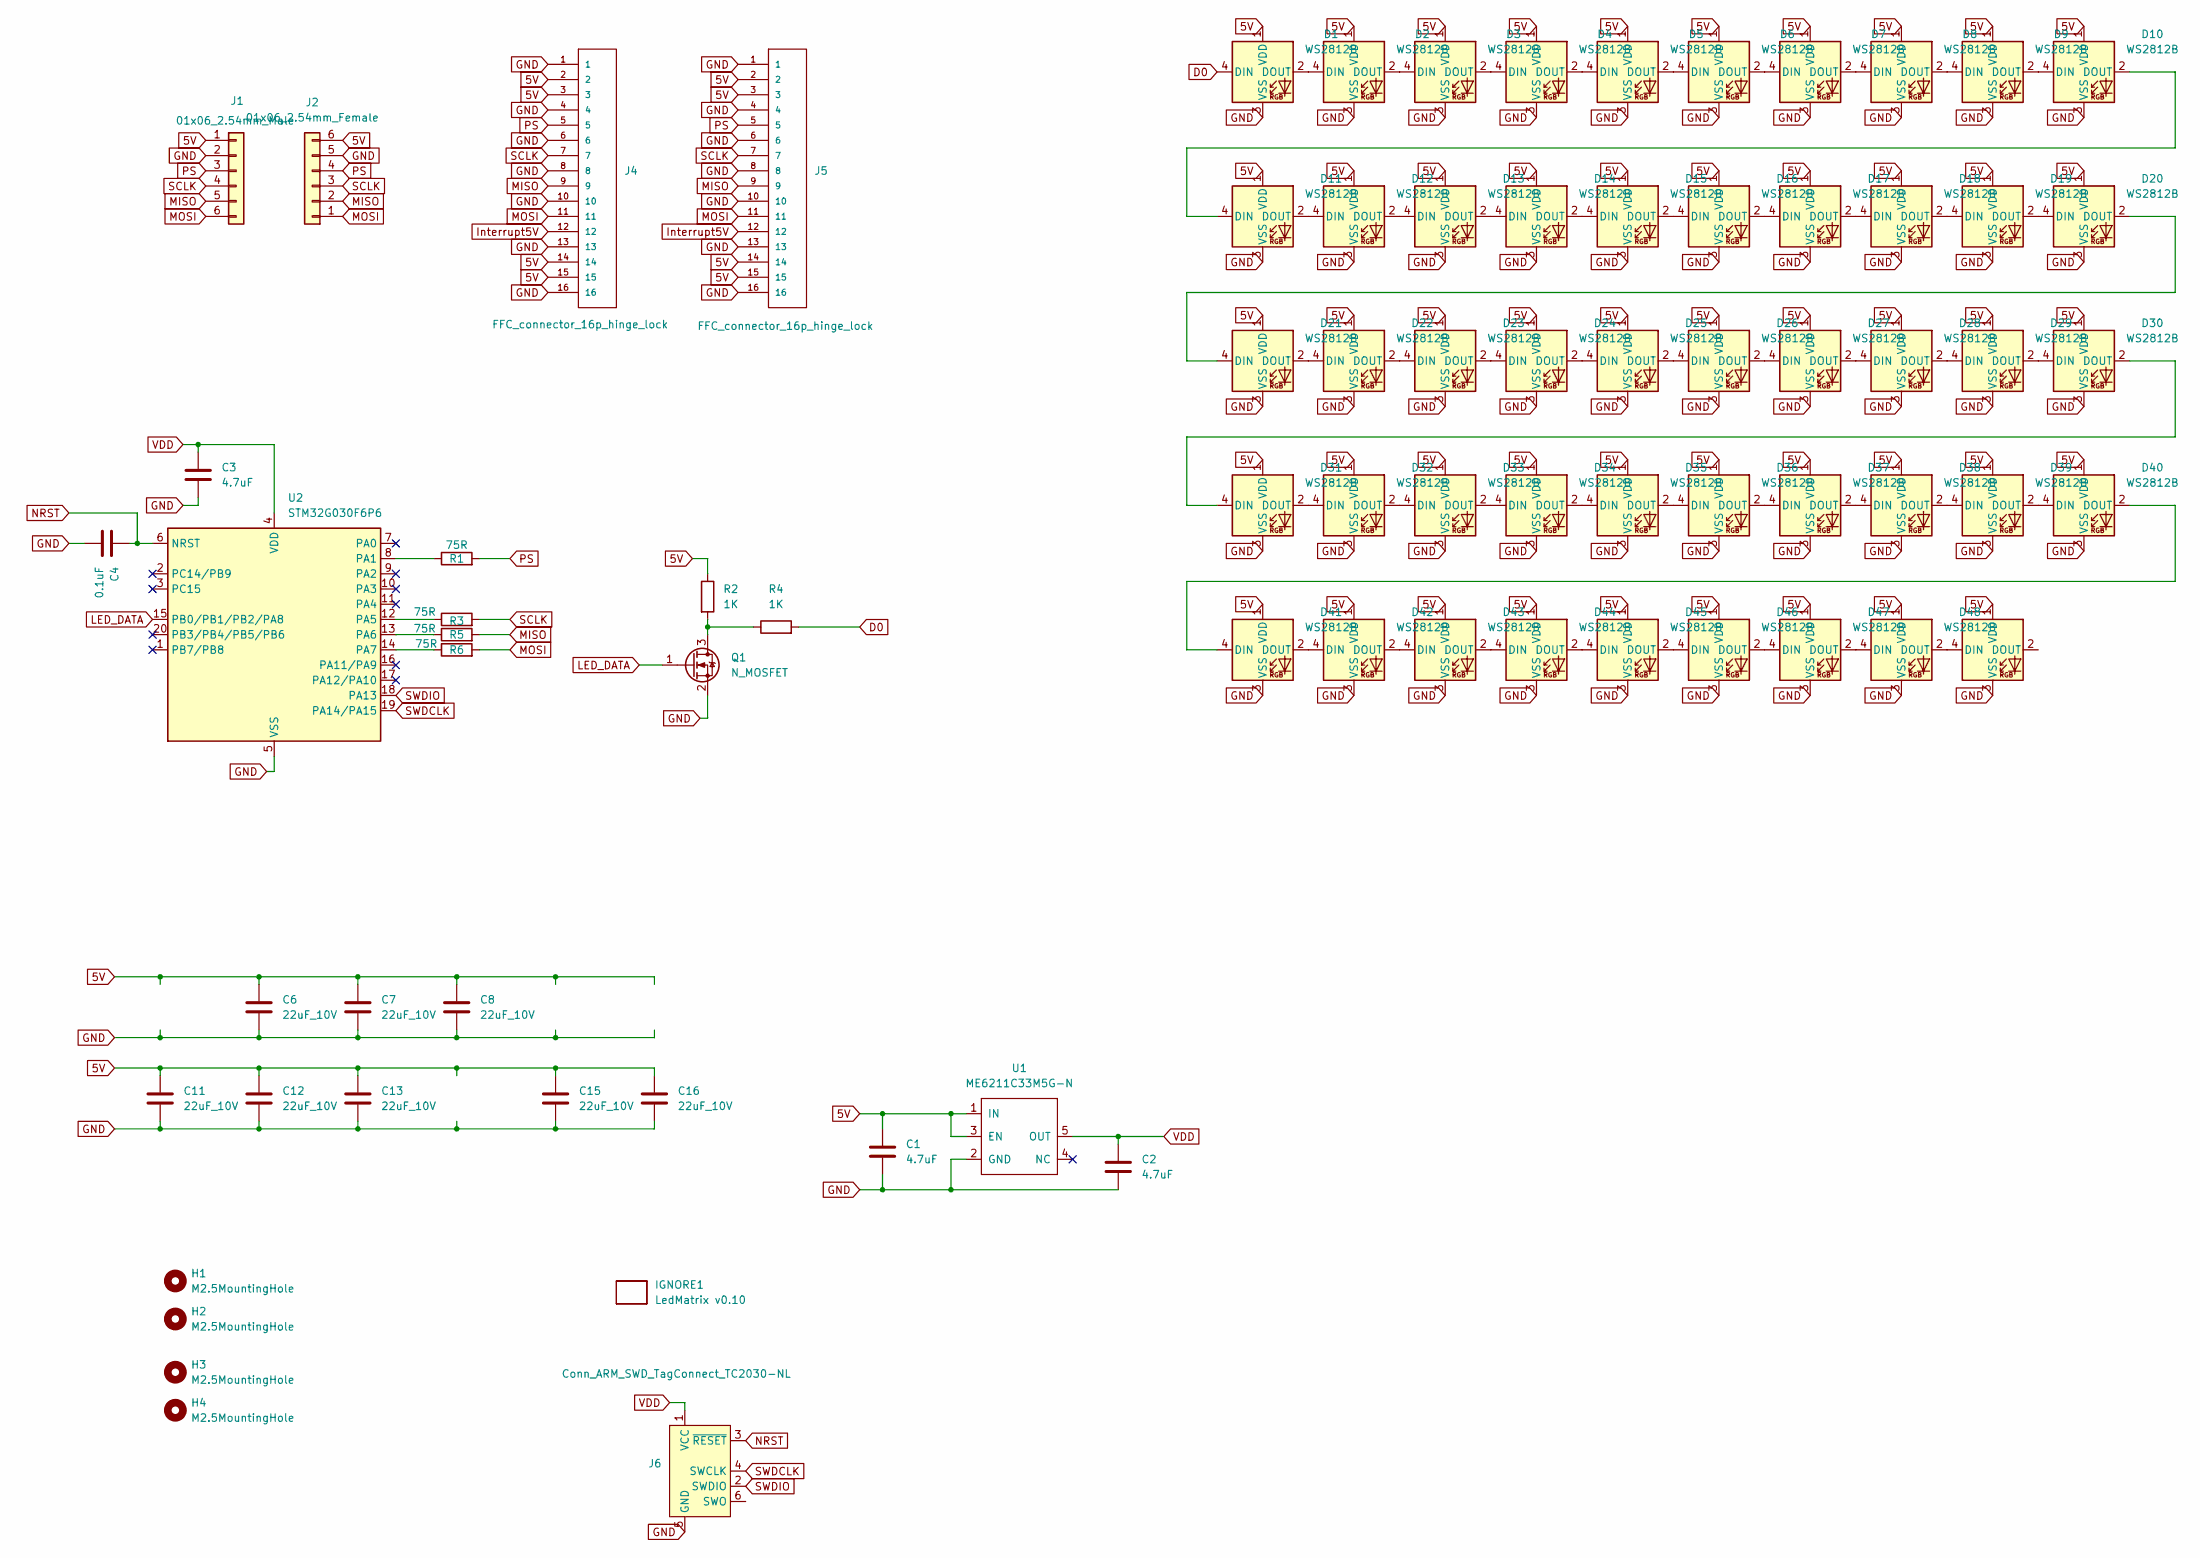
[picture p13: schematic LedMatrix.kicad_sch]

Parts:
C1, C2, C3: 4.7uF; C_0402_1005Metric
C4: 0.1uF; C_0402_1005Metric
C6, C7, C8, C11, C12, C13, C15, C16: 22uF_10V; C_0603_1608Metric
D1, D2, D3, D4, D5, D6, D7, D8, D9, D10, D11, D12, D13, D14, D15, D16, D17, D18, D19, D20, D21, D22, D23, D24, D25, D26, D27, D28, D29, D30, D31, D32, D33, D34, D35, D36, D37, D38, D39, D40, D41, D42, D43, D44, D45, D46, D47, D48, D49: WS2812B; LED_WS2812B_PLCC4_5.0x5.0mm_P3.2mm
H1, H2, H3, H4: M2.5MountingHole; MountingHole_2.7mm_M2.5_ISO7380
IGNORE1: LedMatrix v0.10; BoardText
J1: 01x06_2.54mm_Male
J2: 01x06_2.54mm_Female
J4, J5: FFC_connector_16p_hinge_lock
J6: Conn_ARM_SWD_TagConnect_TC2030-NL; Tag-Connect_TC2030-IDC-NL_2x03_P1.27mm_Vertical
Q1: N_MOSFET; SOT-23
R1, R3, R5, R6: 75R; R_0402_1005Metric
R2, R4: 1K; R_0402_1005Metric
U1: ME6211C33M5G-N; SOT-23-5
U2: STM32G030F6P6; TSSOP-20_4.4x6.5mm_P0.65mm

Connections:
5V: C1.1, C6.1, C7.1, C8.1, C11.1, C12.1, C13.1, C15.1, C16.1, D1.1 (VDD), D2.1 (VDD), D3.1 (VDD), D4.1 (VDD), D5.1 (VDD), D6.1 (VDD), D7.1 (VDD), D8.1 (VDD), D9.1 (VDD), D10.1 (VDD), D11.1 (VDD), D12.1 (VDD), D13.1 (VDD), D14.1 (VDD), D15.1 (VDD), D16.1 (VDD), D17.1 (VDD), D18.1 (VDD), D19.1 (VDD), D20.1 (VDD), D21.1 (VDD), D22.1 (VDD), D23.1 (VDD), D24.1 (VDD), D25.1 (VDD), D26.1 (VDD), D27.1 (VDD), D28.1 (VDD), D29.1 (VDD), D30.1 (VDD), D31.1 (VDD), D32.1 (VDD), D33.1 (VDD), D34.1 (VDD), D35.1 (VDD), D36.1 (VDD), D37.1 (VDD), D38.1 (VDD), D39.1 (VDD), D40.1 (VDD), D41.1 (VDD), D42.1 (VDD), D43.1 (VDD), D44.1 (VDD), D45.1 (VDD), D46.1 (VDD), D47.1 (VDD), D48.1 (VDD), D49.1 (VDD), J1.1, J2.6, J4.2, J4.3, J4.14, J4.15, J5.2, J5.3, J5.14, J5.15, R2.1, U1.1 (IN), U1.3 (EN)
D0: D1.4 (DIN), R4.2
GND: C1.2, C2.2, C3.2, C4.2, C6.2, C7.2, C8.2, C11.2, C12.2, C13.2, C15.2, C16.2, D1.3 (VSS), D2.3 (VSS), D3.3 (VSS), D4.3 (VSS), D5.3 (VSS), D6.3 (VSS), D7.3 (VSS), D8.3 (VSS), D9.3 (VSS), D10.3 (VSS), D11.3 (VSS), D12.3 (VSS), D13.3 (VSS), D14.3 (VSS), D15.3 (VSS), D16.3 (VSS), D17.3 (VSS), D18.3 (VSS), D19.3 (VSS), D20.3 (VSS), D21.3 (VSS), D22.3 (VSS), D23.3 (VSS), D24.3 (VSS), D25.3 (VSS), D26.3 (VSS), D27.3 (VSS), D28.3 (VSS), D29.3 (VSS), D30.3 (VSS), D31.3 (VSS), D32.3 (VSS), D33.3 (VSS), D34.3 (VSS), D35.3 (VSS), D36.3 (VSS), D37.3 (VSS), D38.3 (VSS), D39.3 (VSS), D40.3 (VSS), D41.3 (VSS), D42.3 (VSS), D43.3 (VSS), D44.3 (VSS), D45.3 (VSS), D46.3 (VSS), D47.3 (VSS), D48.3 (VSS), D49.3 (VSS), J1.2, J2.5, J4.1, J4.4, J4.6, J4.8, J4.10, J4.13, J4.16, J5.1, J5.4, J5.6, J5.8, J5.10, J5.13, J5.16, J6.5 (GND), Q1.2 (S), U1.2 (GND), U2.5 (VSS)
Interrupt5V: J4.12, J5.12
LED_DATA: Q1.1 (G), U2.15 (PB0/PB1/PB2/PA8)
MISO: J1.5, J2.2, J4.9, J5.9, R5.2
MOSI: J1.6, J2.1, J4.11, J5.11, R6.2
NRST: C4.1, J6.3 (~RESET), U2.6 (NRST)
unnamed: D1.2 (DOUT), D2.4 (DIN)
unnamed: D2.2 (DOUT), D3.4 (DIN)
unnamed: D3.2 (DOUT), D4.4 (DIN)
unnamed: D4.2 (DOUT), D5.4 (DIN)
unnamed: D5.2 (DOUT), D6.4 (DIN)
unnamed: D6.2 (DOUT), D7.4 (DIN)
unnamed: D7.2 (DOUT), D8.4 (DIN)
unnamed: D8.2 (DOUT), D9.4 (DIN)
unnamed: D9.2 (DOUT), D10.4 (DIN)
unnamed: D10.2 (DOUT), D11.4 (DIN)
unnamed: D11.2 (DOUT), D12.4 (DIN)
unnamed: D12.2 (DOUT), D13.4 (DIN)
unnamed: D13.2 (DOUT), D14.4 (DIN)
unnamed: D14.2 (DOUT), D15.4 (DIN)
unnamed: D15.2 (DOUT), D16.4 (DIN)
unnamed: D16.2 (DOUT), D17.4 (DIN)
unnamed: D17.2 (DOUT), D18.4 (DIN)
unnamed: D18.2 (DOUT), D19.4 (DIN)
unnamed: D19.2 (DOUT), D20.4 (DIN)
unnamed: D20.2 (DOUT), D21.4 (DIN)
unnamed: D21.2 (DOUT), D22.4 (DIN)
unnamed: D22.2 (DOUT), D23.4 (DIN)
unnamed: D23.2 (DOUT), D24.4 (DIN)
unnamed: D24.2 (DOUT), D25.4 (DIN)
unnamed: D25.2 (DOUT), D26.4 (DIN)
unnamed: D26.2 (DOUT), D27.4 (DIN)
unnamed: D27.2 (DOUT), D28.4 (DIN)
unnamed: D28.2 (DOUT), D29.4 (DIN)
unnamed: D29.2 (DOUT), D30.4 (DIN)
unnamed: D30.2 (DOUT), D31.4 (DIN)
unnamed: D31.2 (DOUT), D32.4 (DIN)
unnamed: D32.2 (DOUT), D33.4 (DIN)
unnamed: D33.2 (DOUT), D34.4 (DIN)
unnamed: D34.2 (DOUT), D35.4 (DIN)
unnamed: D35.2 (DOUT), D36.4 (DIN)
unnamed: D36.2 (DOUT), D37.4 (DIN)
unnamed: D37.2 (DOUT), D38.4 (DIN)
unnamed: D38.2 (DOUT), D39.4 (DIN)
unnamed: D39.2 (DOUT), D40.4 (DIN)
unnamed: D40.2 (DOUT), D41.4 (DIN)
unnamed: D41.2 (DOUT), D42.4 (DIN)
unnamed: D42.2 (DOUT), D43.4 (DIN)
unnamed: D43.2 (DOUT), D44.4 (DIN)
unnamed: D44.2 (DOUT), D45.4 (DIN)
unnamed: D45.2 (DOUT), D46.4 (DIN)
unnamed: D46.2 (DOUT), D47.4 (DIN)
unnamed: D47.2 (DOUT), D48.4 (DIN)
unnamed: D48.2 (DOUT), D49.4 (DIN)
unnamed: Q1.3 (D), R2.2, R4.1
unnamed: R1.1, U2.8 (PA1)
unnamed: R3.1, U2.12 (PA5)
unnamed: R5.1, U2.13 (PA6)
unnamed: R6.1, U2.14 (PA7)
PS: J1.3, J2.4, J4.5, J5.5, R1.2
SCLK: J1.4, J2.3, J4.7, J5.7, R3.2
SWDCLK: J6.4 (SWCLK), U2.19 (PA14/PA15)
SWDIO: J6.2 (SWDIO), U2.18 (PA13)
VDD: C2.1, C3.1, J6.1 (VCC), U1.5 (OUT), U2.4 (VDD)

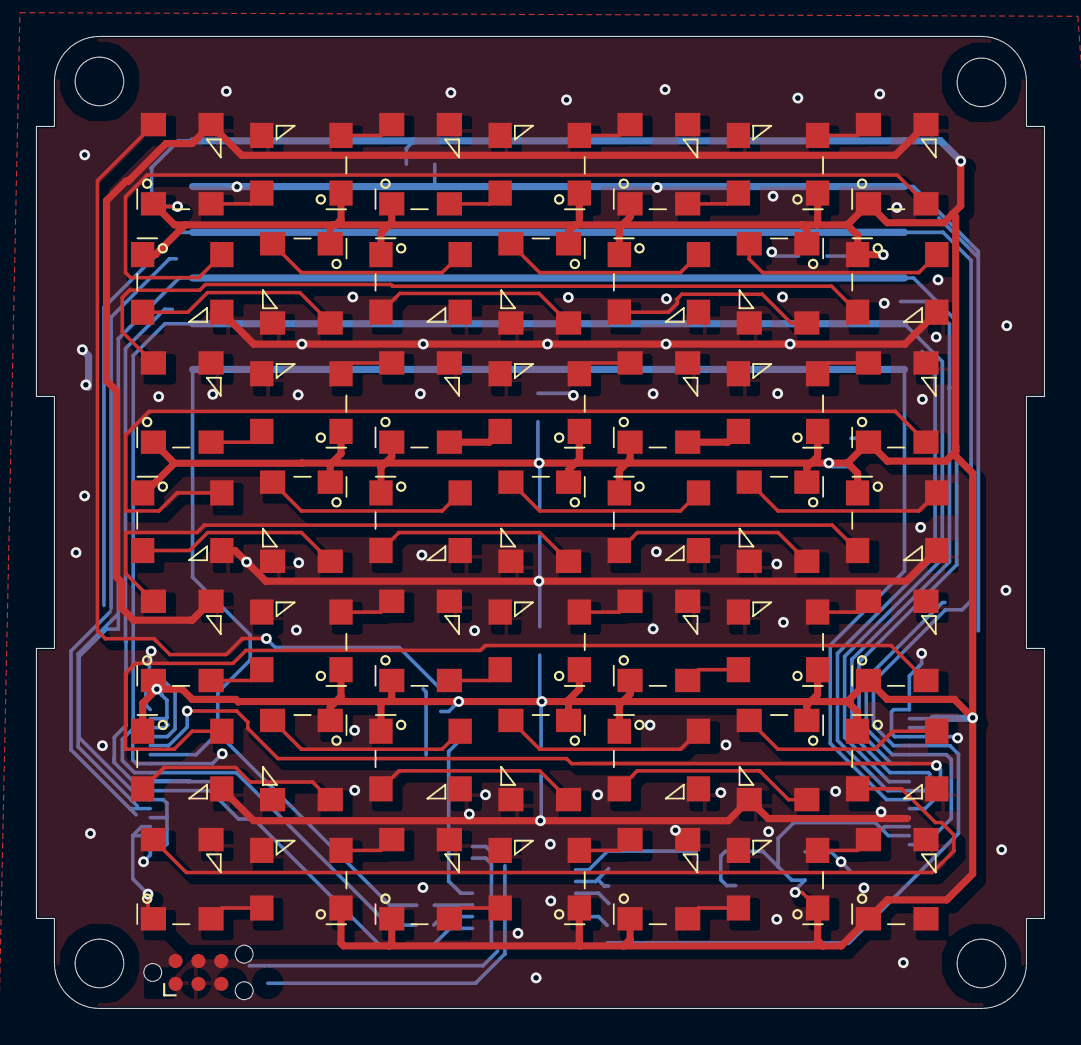
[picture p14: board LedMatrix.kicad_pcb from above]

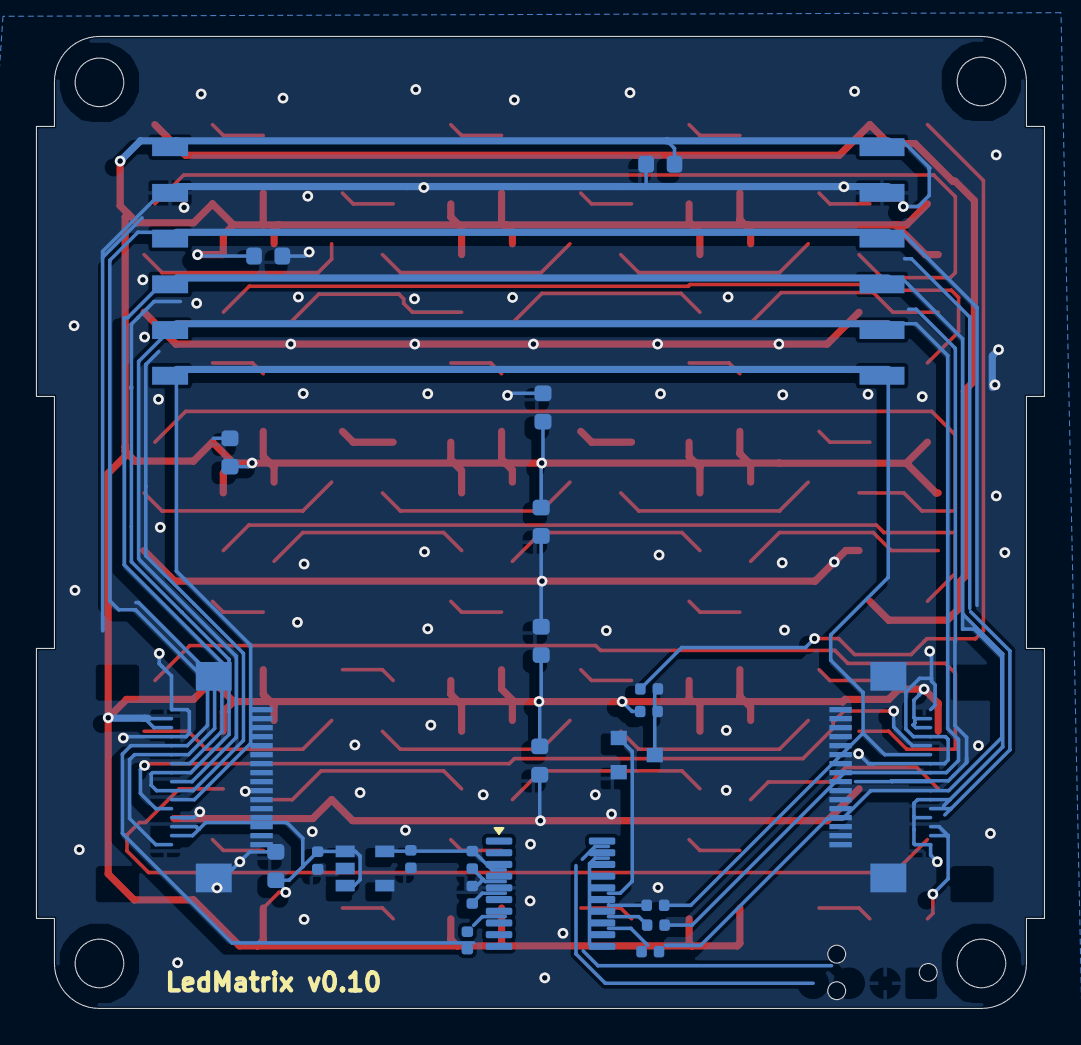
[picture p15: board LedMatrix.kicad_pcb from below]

Board: 4 copper layers, 56.0 x 54.0 mm, 80 parts (25 on the bottom side), 66 nets.

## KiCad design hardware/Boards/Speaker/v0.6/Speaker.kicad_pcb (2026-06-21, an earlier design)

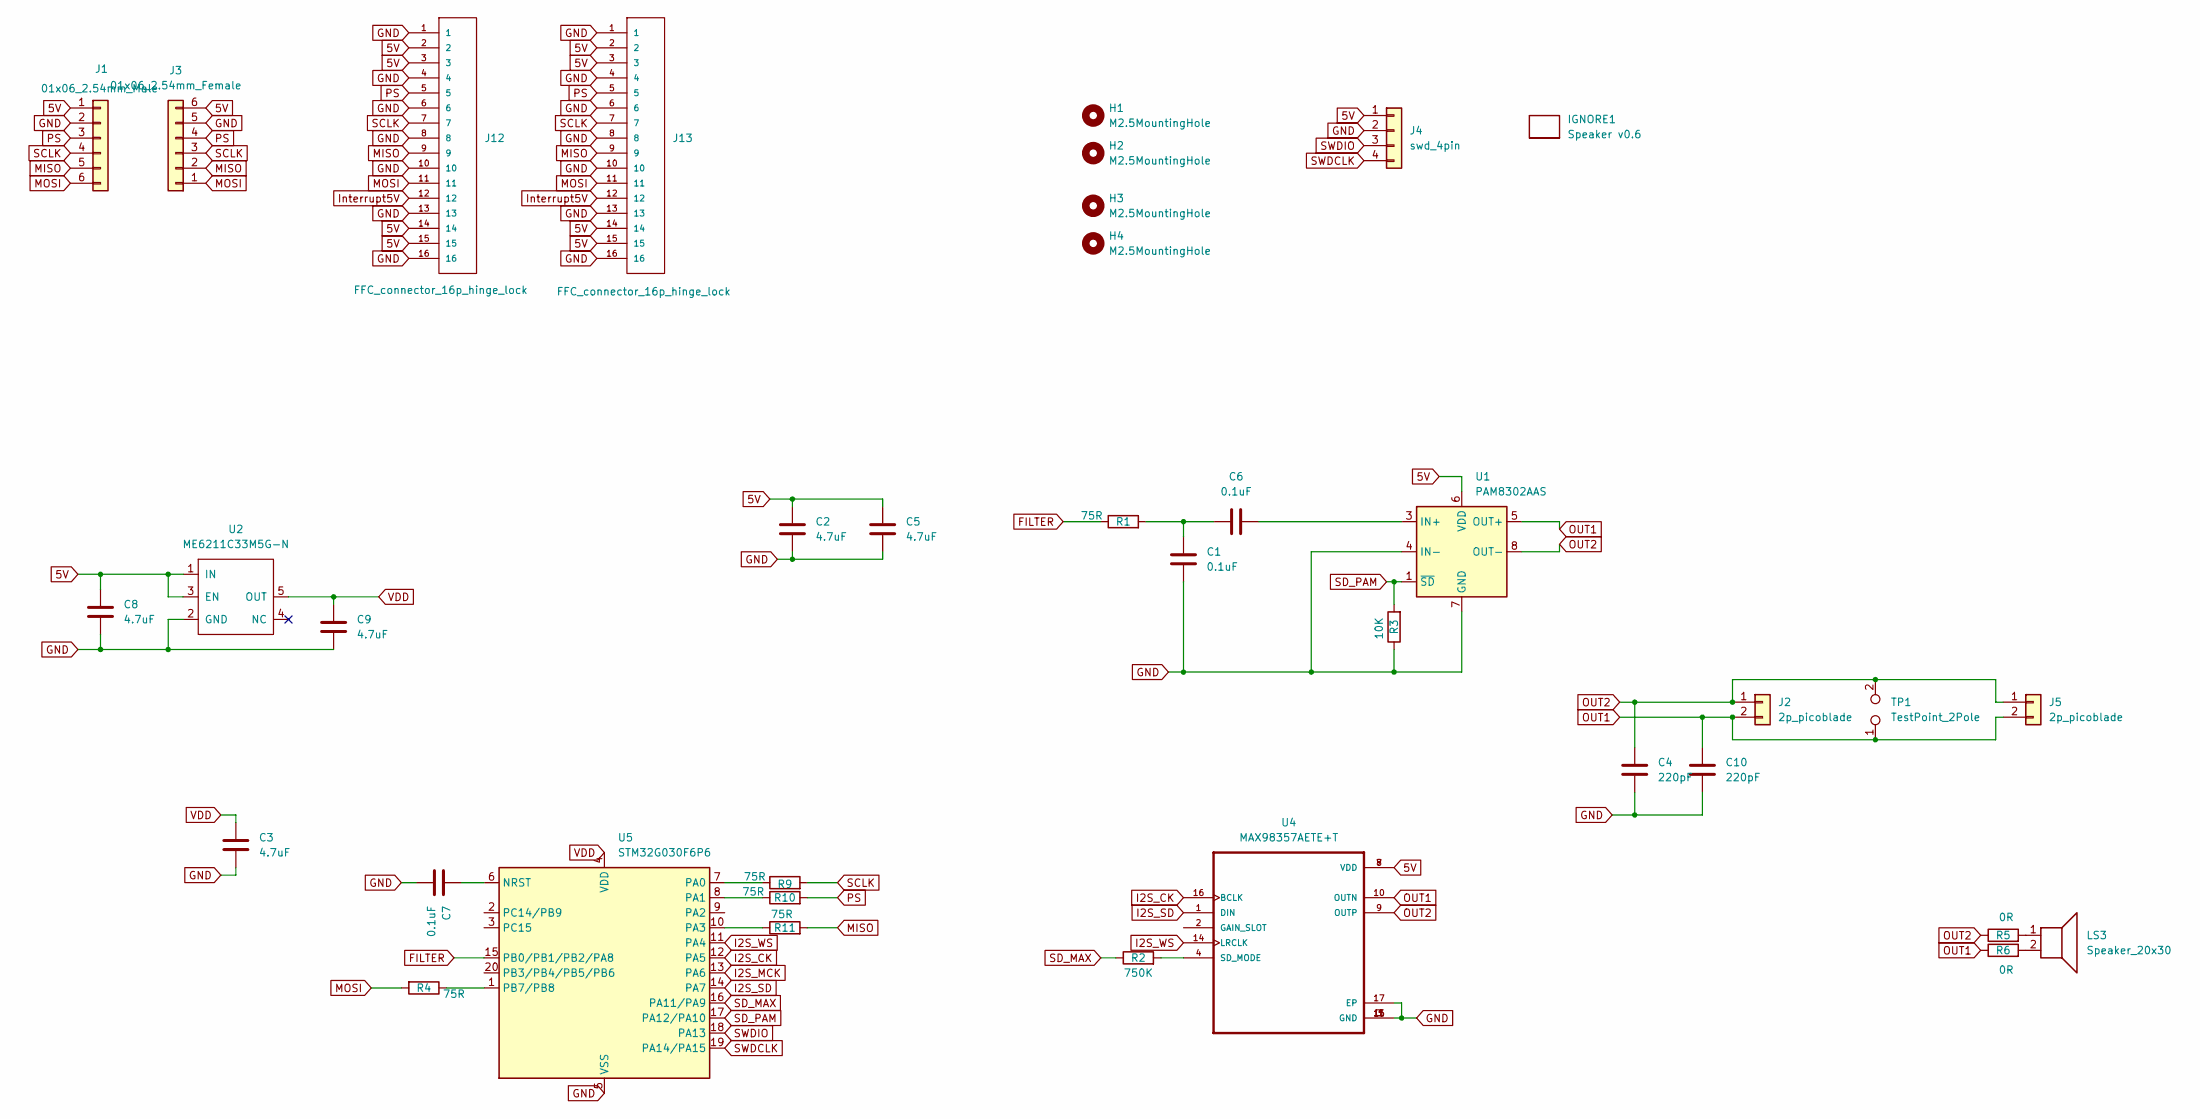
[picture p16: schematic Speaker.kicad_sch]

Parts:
C1, C6, C7: 0.1uF; C_0402_1005Metric
C2, C3, C5, C8, C9: 4.7uF; C_0402_1005Metric
C4, C10: 220pF; C_0402_1005Metric
H1, H2, H3, H4: M2.5MountingHole; MountingHole_2.7mm_M2.5_ISO7380
IGNORE1: Speaker v0.6; BoardText
J1: 01x06_2.54mm_Male
J2, J5: 2p_picoblade; Molex_PicoBlade_53261-0271_1x02-1MP_P1.25mm_Horizontal
J3: 01x06_2.54mm_Female
J4: swd_4pin; swd_header
J12, J13: FFC_connector_16p_hinge_lock
LS3: Speaker_20x30; Speaker1.8x1.8
R1, R4, R9, R10, R11: 75R; R_0402_1005Metric
R2: 750K; R_0402_1005Metric
R3: 10K; R_0402_1005Metric
R5, R6: 0R; R_0402_1005Metric
TP1: TestPoint_2Pole; TestPoint_2Pads_Pitch2.54mm_Drill0.8mm
U1: PAM8302AAS; MSOP-8_3x3mm_P0.65mm
U2: ME6211C33M5G-N; SOT-23-5
U4: MAX98357AETE+T; QFN50P300X300X80-17N
U5: STM32G030F6P6; TSSOP-20_4.4x6.5mm_P0.65mm

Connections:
5V: C2.1, C5.1, C8.1, J1.1, J3.6, J4.1, J12.2, J12.3, J12.14, J12.15, J13.2, J13.3, J13.14, J13.15, U1.6 (VDD), U2.1 (IN), U2.3 (EN), U4.7 (VDD), U4.8 (VDD)
FILTER: R1.1, U5.15 (PB0/PB1/PB2/PA8)
GND: C1.2, C2.2, C3.2, C4.2, C5.2, C7.2, C8.2, C9.2, C10.2, J1.2, J3.5, J4.2, J12.1, J12.4, J12.6, J12.8, J12.10, J12.13, J12.16, J13.1, J13.4, J13.6, J13.8, J13.10, J13.13, J13.16, R3.1, U1.4 (IN-), U1.7 (GND), U2.2 (GND), U4.3 (GND), U4.11 (GND), U4.15 (GND), U4.17 (EP), U5.5 (VSS)
I2S_CK: U4.16 (BCLK), U5.12 (PA5)
I2S_MCK: U5.13 (PA6)
I2S_SD: U4.1 (DIN), U5.14 (PA7)
I2S_WS: U4.14 (LRCLK), U5.11 (PA4)
Interrupt5V: J12.12, J13.12
MISO: J1.5, J3.2, J12.9, J13.9, R11.2
MOSI: J1.6, J3.1, J12.11, J13.11, R4.2
unnamed: C1.1, C6.2, R1.2
unnamed: LS3.1, R5.2
unnamed: LS3.2, R6.2
unnamed: C6.1, U1.3 (IN+)
unnamed: R2.2, U4.4 (SD_MODE)
unnamed: C7.1, U5.6 (NRST)
unnamed: R9.1, U5.7 (PA0)
unnamed: R10.1, U5.8 (PA1)
unnamed: R11.1, U5.10 (PA3)
unnamed: R4.1, U5.1 (PB7/PB8)
OUT1: C10.1, J2.2, J5.2, R6.1, TP1.1, U1.5 (OUT+), U4.10 (OUTN)
OUT2: C4.1, J2.1, J5.1, R5.1, TP1.2, U1.8 (OUT-), U4.9 (OUTP)
PS: J1.3, J3.4, J12.5, J13.5, R10.2
SCLK: J1.4, J3.3, J12.7, J13.7, R9.2
SD_MAX: R2.1, U5.16 (PA11/PA9)
SD_PAM: R3.2, U1.1 (~SD), U5.17 (PA12/PA10)
SWDCLK: J4.4, U5.19 (PA14/PA15)
SWDIO: J4.3, U5.18 (PA13)
VDD: C3.1, C9.1, U2.5 (OUT), U5.4 (VDD)

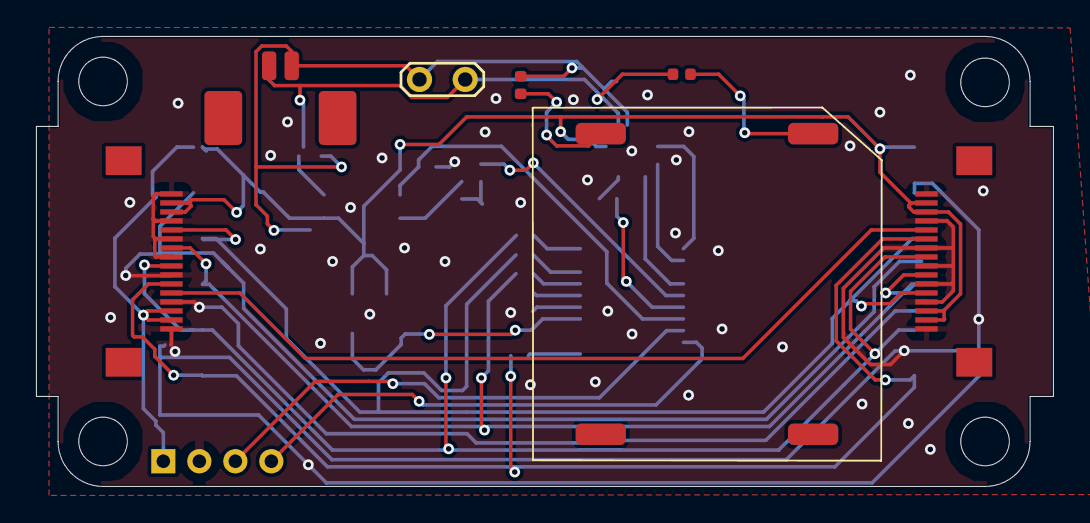
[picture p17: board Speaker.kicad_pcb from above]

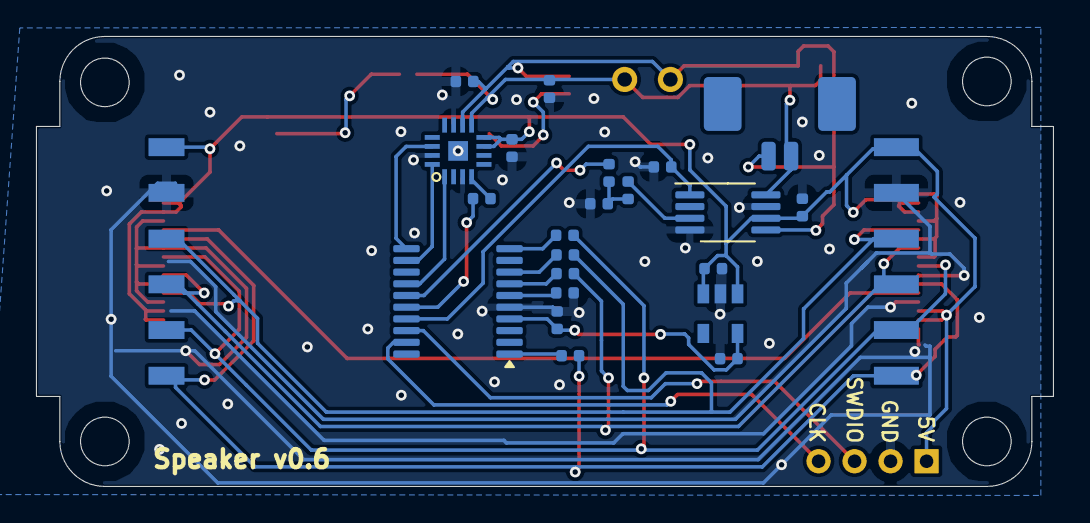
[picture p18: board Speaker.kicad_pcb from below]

Board: 2 copper layers, 56.5 x 25.0 mm, 37 parts (24 on the bottom side), 28 nets.

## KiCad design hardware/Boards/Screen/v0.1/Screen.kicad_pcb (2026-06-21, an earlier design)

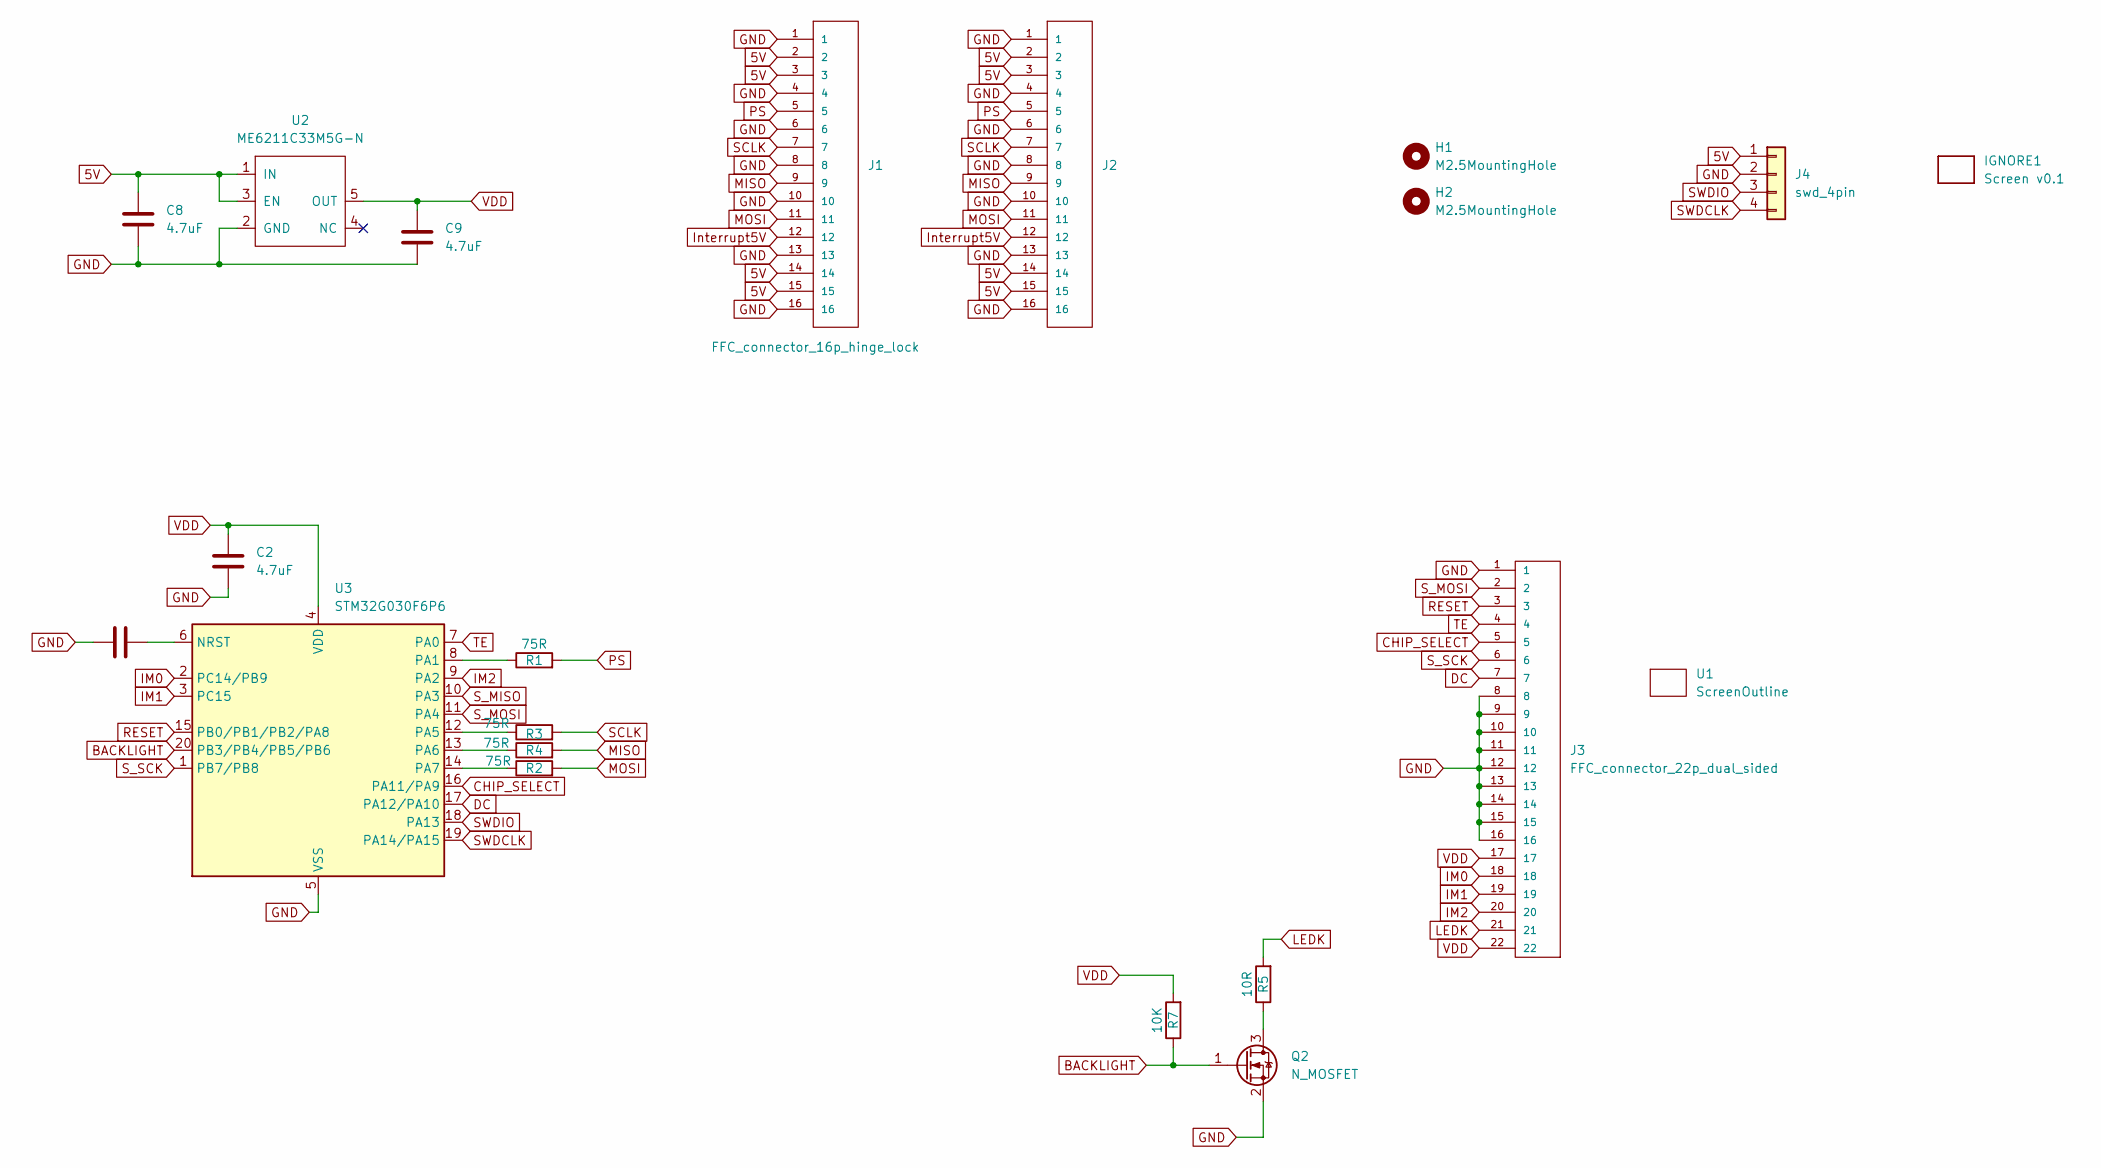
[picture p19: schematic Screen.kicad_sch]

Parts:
C1: 0.1uF; C_0402_1005Metric
C2, C8, C9: 4.7uF; C_0402_1005Metric
H1, H2: M2.5MountingHole; MountingHole_2.7mm_M2.5_ISO7380
IGNORE1: Screen v0.1; BoardText
J1, J2: FFC_connector_16p_hinge_lock
J3: FFC_connector_22p_dual_sided; FFC_connector_22p_hinge_lock
J4: swd_4pin; swd_header
Q2: N_MOSFET; SOT-23
R1, R2, R3, R4: 75R; R_0402_1005Metric
R5: 10R; R_0402_1005Metric
R7: 10K; R_0402_1005Metric
U1: ScreenOutline; 2InchScreen
U2: ME6211C33M5G-N; SOT-23-5
U3: STM32G030F6P6; TSSOP-20_4.4x6.5mm_P0.65mm

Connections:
5V: C8.1, J1.2, J1.3, J1.14, J1.15, J2.2, J2.3, J2.14, J2.15, J4.1, U2.1 (IN), U2.3 (EN)
BACKLIGHT: Q2.1 (G), R7.1, U3.20 (PB3/PB4/PB5/PB6)
CHIP_SELECT: J3.5, U3.16 (PA11/PA9)
DC: J3.7, U3.17 (PA12/PA10)
GND: C1.2, C2.2, C8.2, C9.2, J1.1, J1.4, J1.6, J1.8, J1.10, J1.13, J1.16, J2.1, J2.4, J2.6, J2.8, J2.10, J2.13, J2.16, J3.1, J3.8, J3.9, J3.10, J3.11, J3.12, J3.13, J3.14, J3.15, J3.16, J4.2, Q2.2 (S), U2.2 (GND), U3.5 (VSS)
IM0: J3.18, U3.2 (PC14/PB9)
IM1: J3.19, U3.3 (PC15)
IM2: J3.20, U3.9 (PA2)
Interrupt5V: J1.12, J2.12
LEDK: J3.21, R5.2
MISO: J1.9, J2.9, R4.2
MOSI: J1.11, J2.11, R2.2
unnamed: Q2.3 (D), R5.1
unnamed: C1.1, U3.6 (NRST)
unnamed: R1.1, U3.8 (PA1)
unnamed: R3.1, U3.12 (PA5)
unnamed: R4.1, U3.13 (PA6)
unnamed: R2.1, U3.14 (PA7)
PS: J1.5, J2.5, R1.2
RESET: J3.3, U3.15 (PB0/PB1/PB2/PA8)
SCLK: J1.7, J2.7, R3.2
SWDCLK: J4.4, U3.19 (PA14/PA15)
SWDIO: J4.3, U3.18 (PA13)
S_MISO: U3.10 (PA3)
S_MOSI: J3.2, U3.11 (PA4)
S_SCK: J3.6, U3.1 (PB7/PB8)
TE: J3.4, U3.7 (PA0)
VDD: C2.1, C9.1, J3.17, J3.22, R7.2, U2.5 (OUT), U3.4 (VDD)

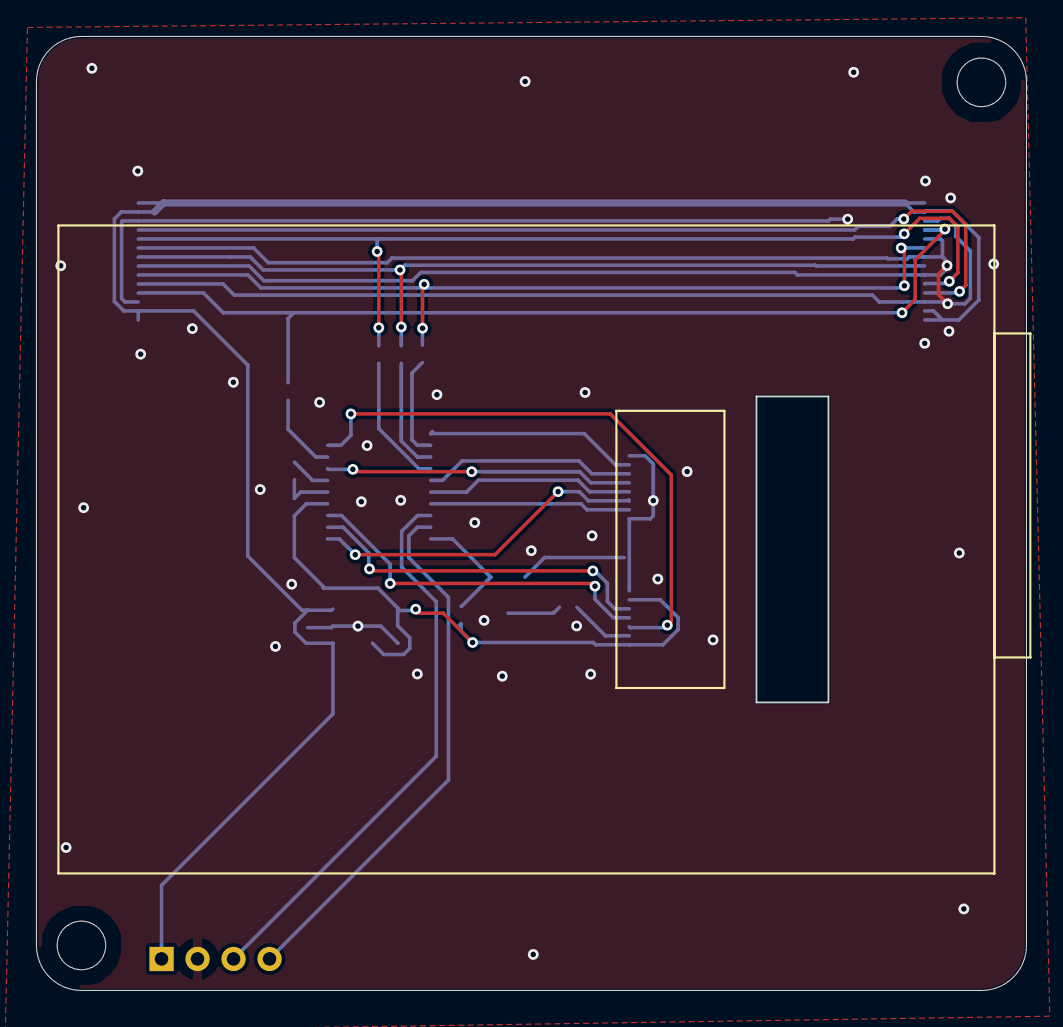
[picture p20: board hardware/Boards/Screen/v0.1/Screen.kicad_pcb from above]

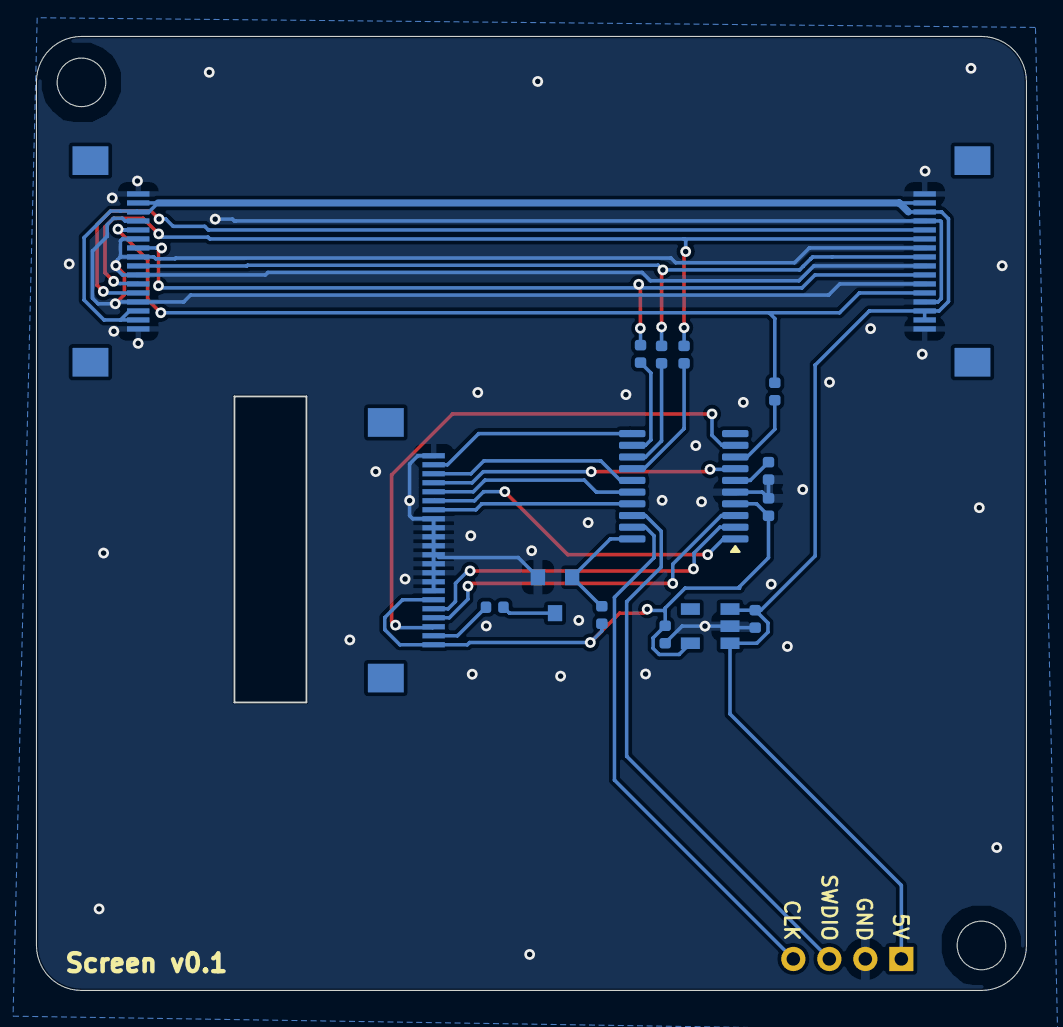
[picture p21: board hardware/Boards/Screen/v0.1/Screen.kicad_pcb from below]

Board: 2 copper layers, 55.0 x 53.0 mm, 21 parts (16 on the bottom side), 27 nets.

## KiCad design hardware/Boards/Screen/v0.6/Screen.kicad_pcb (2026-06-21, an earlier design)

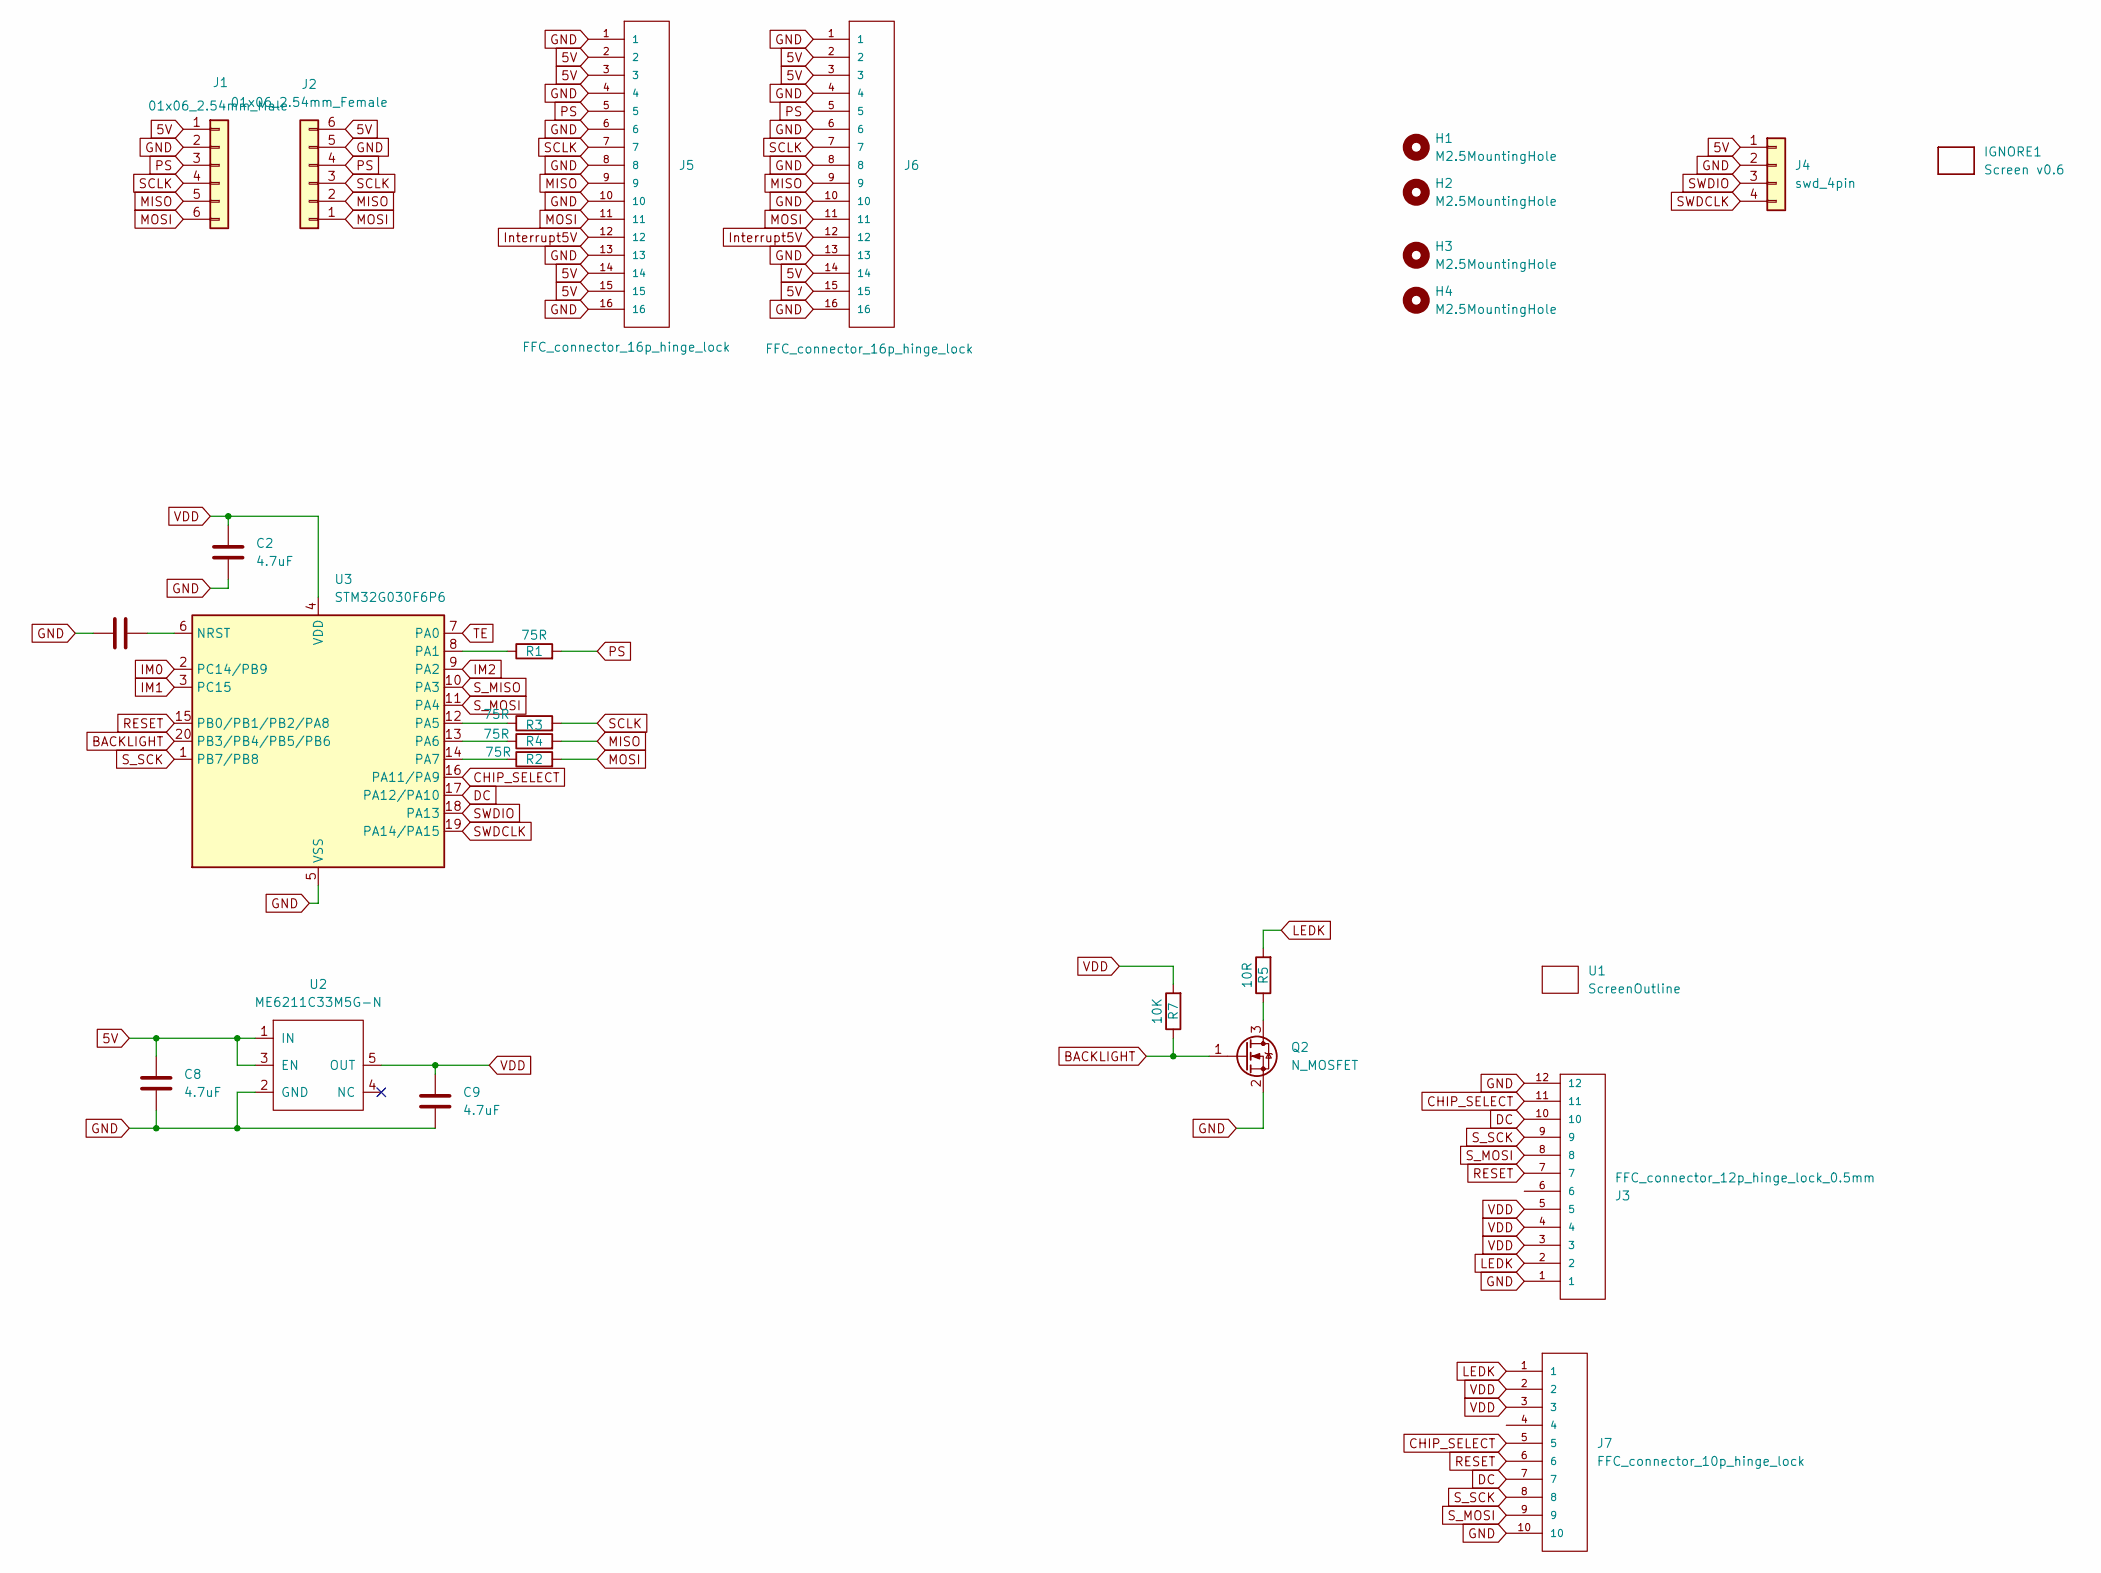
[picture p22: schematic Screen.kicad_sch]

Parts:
C1: 0.1uF; C_0402_1005Metric
C2, C8, C9: 4.7uF; C_0402_1005Metric
H1, H2, H3, H4: M2.5MountingHole; MountingHole_2.7mm_M2.5_ISO7380
IGNORE1: Screen v0.6; BoardText
J1: 01x06_2.54mm_Male
J2: 01x06_2.54mm_Female
J3: FFC_connector_12p_hinge_lock_0.5mm
J4: swd_4pin; swd_header
J5, J6: FFC_connector_16p_hinge_lock
J7: FFC_connector_10p_hinge_lock
Q2: N_MOSFET; SOT-23
R1, R2, R3, R4: 75R; R_0402_1005Metric
R5: 10R; R_0402_1005Metric
R7: 10K; R_0402_1005Metric
U1: ScreenOutline; 2InchScreen
U2: ME6211C33M5G-N; SOT-23-5
U3: STM32G030F6P6; TSSOP-20_4.4x6.5mm_P0.65mm

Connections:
5V: C8.1, J1.1, J2.6, J4.1, J5.2, J5.3, J5.14, J5.15, J6.2, J6.3, J6.14, J6.15, U2.1 (IN), U2.3 (EN)
BACKLIGHT: Q2.1 (G), R7.1, U3.20 (PB3/PB4/PB5/PB6)
CHIP_SELECT: J3.11, J7.5, U3.16 (PA11/PA9)
DC: J3.10, J7.7, U3.17 (PA12/PA10)
GND: C1.2, C2.2, C8.2, C9.2, J1.2, J2.5, J3.1, J3.12, J4.2, J5.1, J5.4, J5.6, J5.8, J5.10, J5.13, J5.16, J6.1, J6.4, J6.6, J6.8, J6.10, J6.13, J6.16, J7.10, Q2.2 (S), U2.2 (GND), U3.5 (VSS)
IM0: U3.2 (PC14/PB9)
IM1: U3.3 (PC15)
IM2: U3.9 (PA2)
Interrupt5V: J5.12, J6.12
LEDK: J3.2, J7.1, R5.2
MISO: J1.5, J2.2, J5.9, J6.9, R4.2
MOSI: J1.6, J2.1, J5.11, J6.11, R2.2
unnamed: Q2.3 (D), R5.1
unnamed: C1.1, U3.6 (NRST)
unnamed: R1.1, U3.8 (PA1)
unnamed: R3.1, U3.12 (PA5)
unnamed: R4.1, U3.13 (PA6)
unnamed: R2.1, U3.14 (PA7)
PS: J1.3, J2.4, J5.5, J6.5, R1.2
RESET: J3.7, J7.6, U3.15 (PB0/PB1/PB2/PA8)
SCLK: J1.4, J2.3, J5.7, J6.7, R3.2
SWDCLK: J4.4, U3.19 (PA14/PA15)
SWDIO: J4.3, U3.18 (PA13)
S_MISO: U3.10 (PA3)
S_MOSI: J3.8, J7.9, U3.11 (PA4)
S_SCK: J3.9, J7.8, U3.1 (PB7/PB8)
TE: U3.7 (PA0)
VDD: C2.1, C9.1, J3.3, J3.4, J3.5, J7.2, J7.3, R7.2, U2.5 (OUT), U3.4 (VDD)



Board: 2 copper layers, 56.0 x 54.0 mm, 26 parts (19 on the bottom side), 23 nets.

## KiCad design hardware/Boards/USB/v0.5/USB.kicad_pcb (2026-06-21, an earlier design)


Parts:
C1, C2, C5, C8, C9: 4.7uF; C_0402_1005Metric
C4: 0.1uF; C_0402_1005Metric
C6, C7: 12pF; C_0402_1005Metric
H1, H2: M2.5MountingHole; MountingHole_2.7mm_M2.5_ISO7380
IC1: USBLC6-4SC6; SOT-23-6; Manufacturer_Part_Number USBLC6-2P6
IGNORE1: USB v0.5; BoardText
J1: 01x06_2.54mm_Male
J2: USB_C_connector_16P; USB_C_Receptacle_16P
J3: 01x06_2.54mm_Female
J4: swd_4pin; swd_header
J5, J6: FFC_connector_16p_hinge_lock
R1, R2: 5.1K; R_0402_1005Metric
R4, R5, R6, R7: 75R; R_0402_1005Metric
R12: 1.5K; R_0402_1005Metric
U1: STM32F103C8T6; LQFP-48_7x7mm_P0.5mm
U2: ME6211C33M5G-N; SOT-23-5
Y2: Crystal_16M_small; Crystal_SMD_2016-4Pin_2.0x1.6mm

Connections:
5V: C8.1, IC1.5 (VBUS), J1.1, J2.A4 (VBUS), J2.A9 (VBUS), J2.B4 (VBUS), J2.B9 (VBUS), J3.6, J4.1, J5.2, J5.3, J5.14, J5.15, J6.2, J6.3, J6.14, J6.15, U2.1 (IN), U2.3 (EN)
GND: C1.2, C2.2, C4.1, C5.2, C6.1, C7.1, C8.2, C9.2, IC1.2 (GND), J1.2, J2.A1 (GND), J2.A12 (GND), J2.B1 (GND), J2.B12 (GND), J2.S1 (SHIELD), J3.5, J4.2, J5.1, J5.4, J5.6, J5.8, J5.10, J5.13, J5.16, J6.1, J6.4, J6.6, J6.8, J6.10, J6.13, J6.16, R1.2, R2.1, U1.8 (VSSA), U1.23 (VSS), U1.35 (VSS), U1.44 (BOOT0), U1.47 (VSS), U2.2 (GND), Y2.2 (GND), Y2.4 (GND)
Interrupt5V: J5.12, J6.12
MISO: J1.5, J3.2, J5.9, J6.9, R6.2
MISO_UC: R6.1, U1.40 (PB4)
MOSI: J1.6, J3.1, J5.11, J6.11, R4.2
MOSI_UC: R4.1, U1.41 (PB5)
unnamed: J2.A5 (CC1), R1.1
unnamed: J2.B5 (CC2), R2.2
unnamed: C4.2, U1.7 (NRST)
OSC_IN: C6.2, U1.5 (PD0), Y2.1
OSC_OUT: C7.2, U1.6 (PD1), Y2.3
PS: J1.3, J3.4, J5.5, J6.5, R5.2
PS_UC: R5.1, U1.29 (PA8)
SCLK: J1.4, J3.3, J5.7, J6.7, R7.2
SCLK_UC: R7.1, U1.39 (PB3)
SWDCLK: J4.4, U1.37 (PA14)
SWDIO: J4.3, U1.34 (PA13)
USB_D+: IC1.3 (I/O2), J2.A6 (D+), J2.B6 (D+), R12.1, U1.33 (PA12)
USB_D-: IC1.1 (I/O1), J2.A7 (D-), J2.B7 (D-), U1.32 (PA11)
VDD: C1.1, C2.1, C5.1, C9.1, R12.2, U1.1 (VBAT), U1.9 (VDDA), U1.24 (VDD), U1.36 (VDD), U1.48 (VDD), U2.5 (OUT)



Board: 4 copper layers, 27.0 x 25.0 mm, 28 parts (2 on the bottom side), 21 nets.

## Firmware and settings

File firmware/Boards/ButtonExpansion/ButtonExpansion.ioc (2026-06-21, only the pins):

Mcu.UserName=STM32G030K6Tx
PA0.Signal=SPI2_SCK
PA1.Signal=GPXTI1
PA10.Signal=SPI2_MOSI
PA13.Signal=SYS_SWDIO
PA14-BOOT0.Signal=SYS_SWCLK
PA15.Signal=GPIO_Input
PA2.Signal=GPIO_Input
PA3.Signal=GPIO_Input
PA4.Signal=GPIO_Input
PA5.Signal=GPIO_Input
PA6.Signal=GPIO_Input
PA7.Signal=GPIO_Input
PA8.Signal=GPIO_Input
PA9.Signal=SPI2_MISO
PB0.Signal=GPIO_Input
PB1.Signal=GPIO_Input
PB2.Signal=GPIO_Input
PB3.Signal=GPIO_Input
PB4.Signal=GPIO_Input
PB5.Signal=GPIO_Input
PB6.Signal=GPIO_Input
PB7.Signal=GPIO_Input
PB8.Signal=GPIO_Input
PB9.Signal=GPIO_Input

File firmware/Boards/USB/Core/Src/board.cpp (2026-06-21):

/*
 * Copyright © 2024 - 2024 Sean Bremner. All rights reserved.
 *
 * USB master board, ported to the C++ FieldProtocol + MicroBus libraries.
 *
 * Layering:
 *   - The daemon (host PC) talks to us over USB (CDC). DaemonUsbInterface
 *     adapts that link to fp::FpInterface.
 *   - The microbus (SPI) link to the field nodes is driven by the C++
 *     microbus::Master (see stm32F1SpiMaster). MicrobusInterface adapts it to
 *     fp::FpInterface.
 *   - fp::Master bridges daemon <-> microbus and also hosts this board's own
 *     fields via fp::Node.
 */

#include <cstdint>
#include <cstring>

#include "stm32f1xx_hal.h"
#include "usbd_cdc_if.h"

#include "FieldProtocol/fpCommon.hpp"
#include "FieldProtocol/fpMaster.hpp"
#include "FieldProtocol/fpNode.hpp"
#include "microbus/microbus.hpp"

#include "stm32/stm32F1SpiMaster.hpp"
#include "Libraries/myAssert.h"
#include "Libraries/useful.h"

#include "project.h"

extern SPI_HandleTypeDef hspi1;
extern TIM_HandleTypeDef htim1;
extern TIM_HandleTypeDef htim2;
extern USBD_HandleTypeDef hUsbDeviceFS;

// The daemon packet is the largest thing on the USB link.
static constexpr uint16_t kMaxDaemonPacketSize = fp::kMaxDaemonPacketSize;

// ==================================== //
// Buffer functions - TODO: put somewhere common

struct PacketBuffer {
    uint16_t start;
    uint16_t end;
    uint16_t size;
    uint8_t* data;
    uint32_t maxLen;
};

static uint8_t usbTxBufferPackets[MAX_USB_TX_PACKETS * kMaxDaemonPacketSize] = {0};
static uint8_t usbRxBufferPackets[MAX_USB_RX_PACKETS * kMaxDaemonPacketSize] = {0};
static uint16_t usbTxPacketSizes[MAX_USB_TX_PACKETS] = {0};
static uint16_t usbRxPacketSizes[MAX_USB_RX_PACKETS] = {0};

static PacketBuffer usbTxBuffer = {0, 0, MAX_USB_TX_PACKETS, usbTxBufferPackets, 0};
static PacketBuffer usbRxBuffer = {0, 0, MAX_USB_RX_PACKETS, usbRxBufferPackets, 0};

static uint64_t usbRxFullCount = 0;
static uint32_t sbmaxUsbRxLevel = 0;
uint64_t numUsbRxPackets = 0;
uint64_t numUsbFpRxPackets = 0;

static bool usbTxAllocated = false;

static uint8_t* usbTxBufferAllocateTxPacket() {
    myAssert(usbTxAllocated == false, "");
    if (fp::circularBufferFull(usbTxBuffer.start, usbTxBuffer.end, usbTxBuffer.size)) {
        return nullptr;
    }
    usbTxAllocated = true;
    return &usbTxBuffer.data[kMaxDaemonPacketSize * usbTxBuffer.end];
}

static void usbTxSubmitAllocatedTxPacket(uint16_t packetSize) {
    usbTxPacketSizes[usbTxBuffer.end] = packetSize;
    usbTxBuffer.end = fp::incrAndWrap(usbTxBuffer.end, 1, usbTxBuffer.size);
    usbTxAllocated = false;
}

static uint8_t* usbPeekRxPacket(uint16_t& numBytes, uint8_t& srcNodeId) {
    if (fp::circularBufferEmpty(usbRxBuffer.start, usbRxBuffer.end, usbRxBuffer.size)) {
        return nullptr;
    }
    numBytes = usbRxPacketSizes[usbRxBuffer.start];
    srcNodeId = 0;
    return &usbRxBuffer.data[kMaxDaemonPacketSize * usbRxBuffer.start];
}

static bool usbPopRxPacket() {
    myAssert(!fp::circularBufferEmpty(usbRxBuffer.start, usbRxBuffer.end, usbRxBuffer.size), "");
    usbRxBuffer.start = fp::incrAndWrap(usbRxBuffer.start, 1, usbRxBuffer.size);
    return true;
}

// ==================================== //
// USB rx reassembly

static bool usbTransmissionInProgress() {
    USBD_CDC_HandleTypeDef* hcdc = (USBD_CDC_HandleTypeDef*)hUsbDeviceFS.pClassData;
    return hcdc->TxState != 0;
}

static uint32_t usbRxCurrentPacketBytesProcessed = 0;  // Length processed so far
static uint32_t usbRxCurrentPacketSize = 0;
uint8_t callDepth = 0;
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

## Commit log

2026-06-21 Initial public release
    MakerTiles: modular STM32 electronic-tile system — hardware (KiCad),
    firmware, the MicroBus + Field Protocol stack, and the Python daemon.
    [Battery-B_Cu.gbl, Battery-B_Mask.gbs, Battery-B_Paste.gbp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]
2026-06-21 Exclude vendored STM32 HAL drivers from language stats
    Each board ships a full copy of ST's CMSIS/HAL drivers, ~95 MB of
    ST-authored C total, which made GitHub report the repo as ~99% C. Mark
    those trees linguist-vendored so the language bar reflects project code.
2026-06-21 Exclude hardware and per-board firmware from language stats
    Mark all of hardware/ and firmware/ as linguist-vendored, re-including
    only the shared firmware/Libraries/. The language bar now reflects the
    project's own software rather than KiCad designs and vendored STM32 code.
